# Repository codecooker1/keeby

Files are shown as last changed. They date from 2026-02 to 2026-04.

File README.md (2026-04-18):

# keeby
A custom ergonomic split keyboard made for HackClub Blueprint based on Corne, Lily58 and Sofle V2

# Routing PCB
more detailed svg and pdf available in PCB/plot

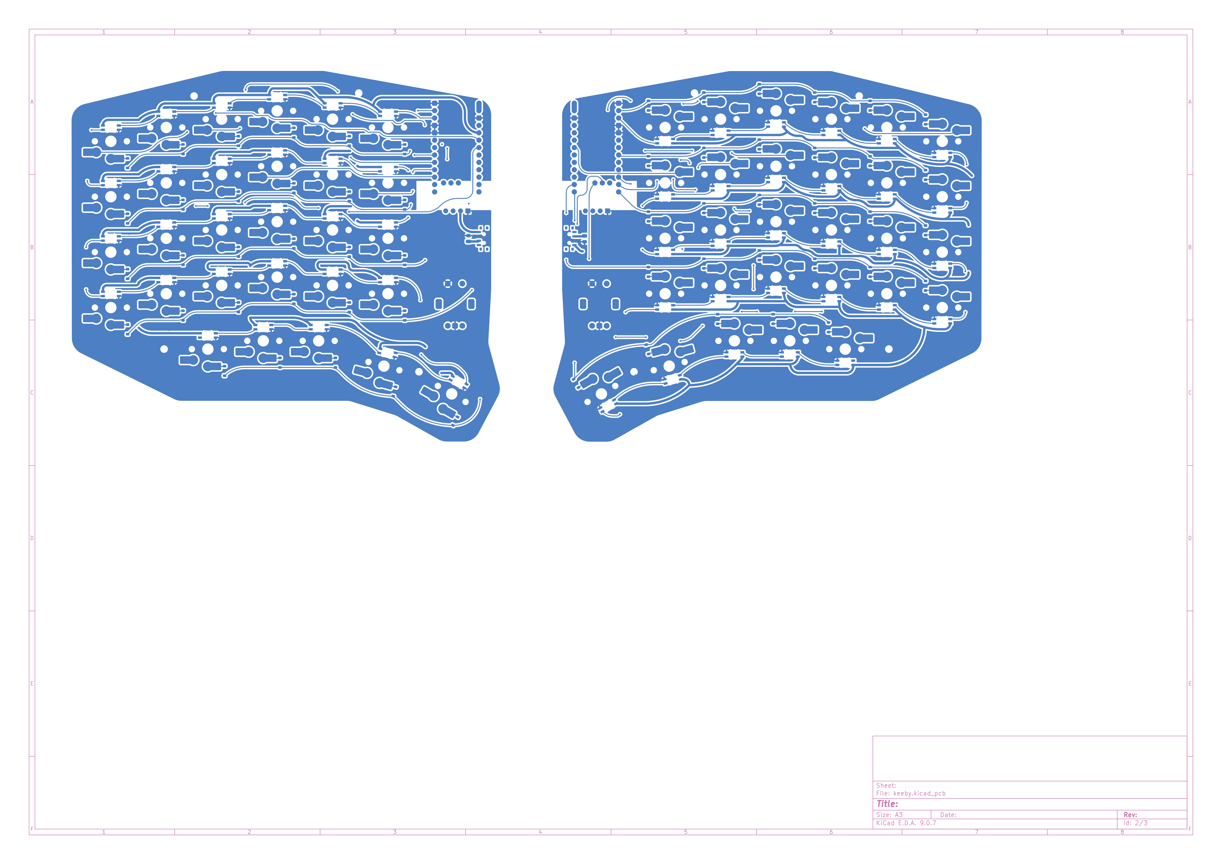
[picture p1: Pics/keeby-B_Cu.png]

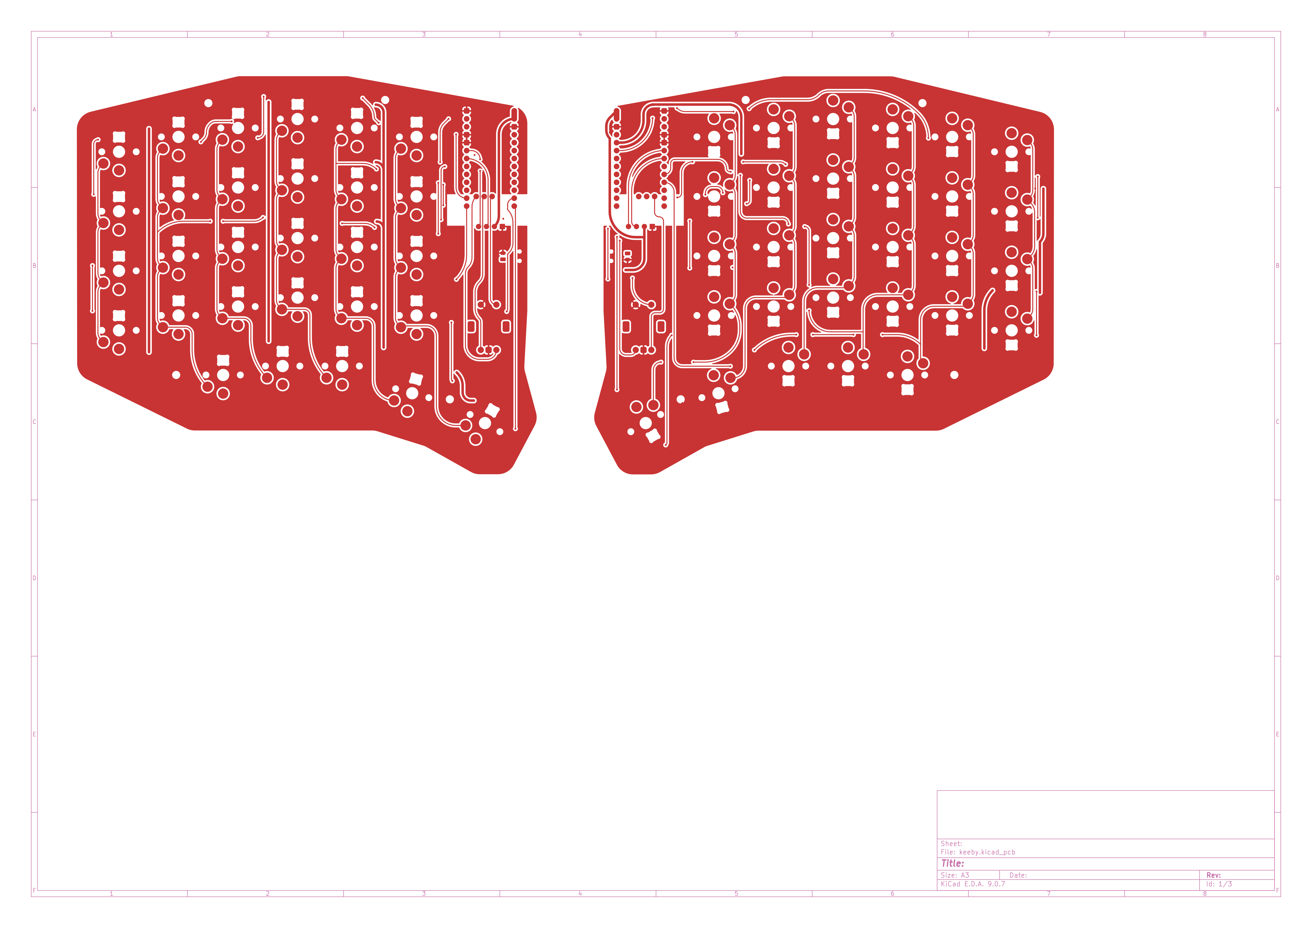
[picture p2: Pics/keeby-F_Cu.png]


# Schematic for the right half
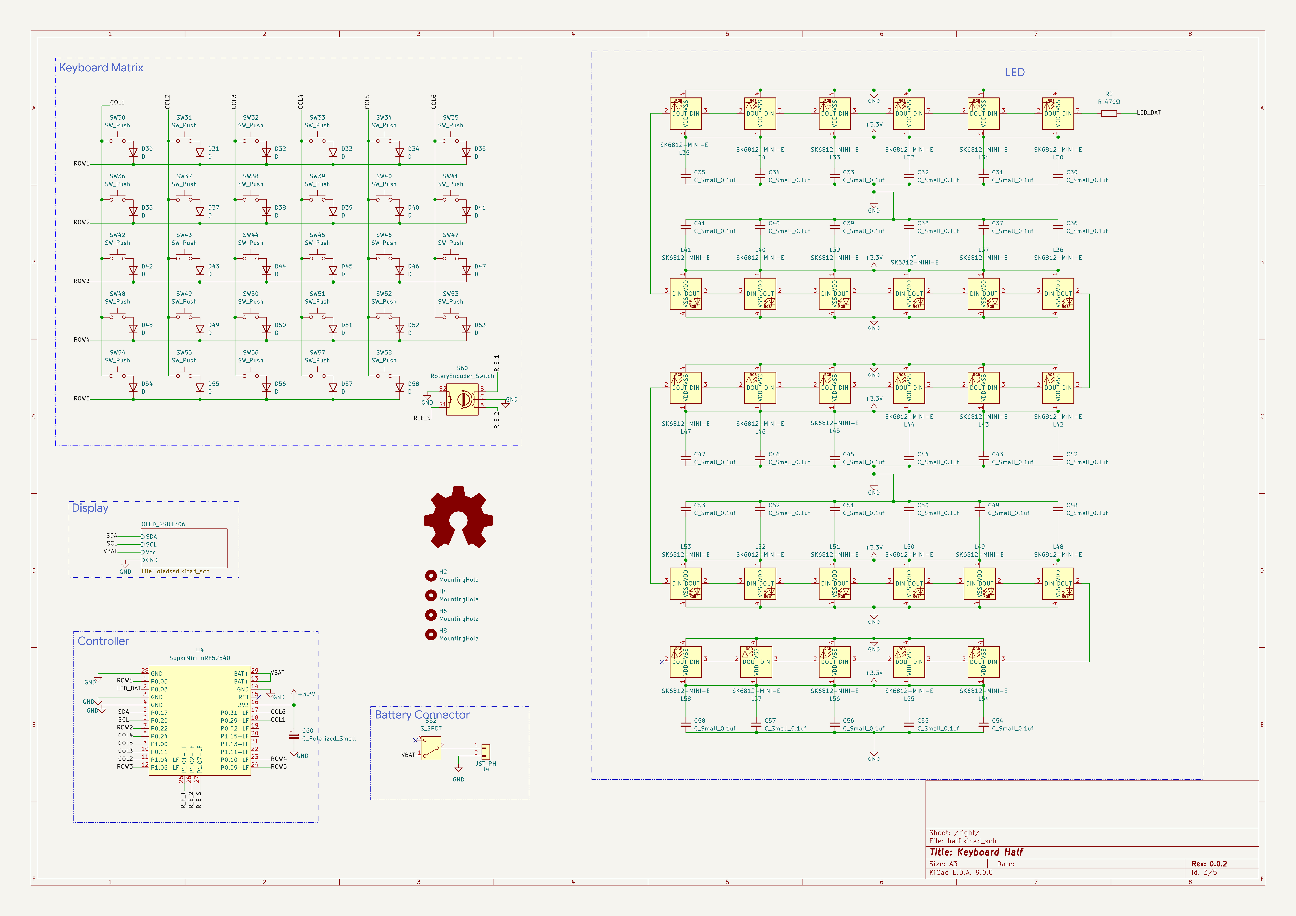
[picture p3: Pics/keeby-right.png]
keeb-right


# Schematic for the left half
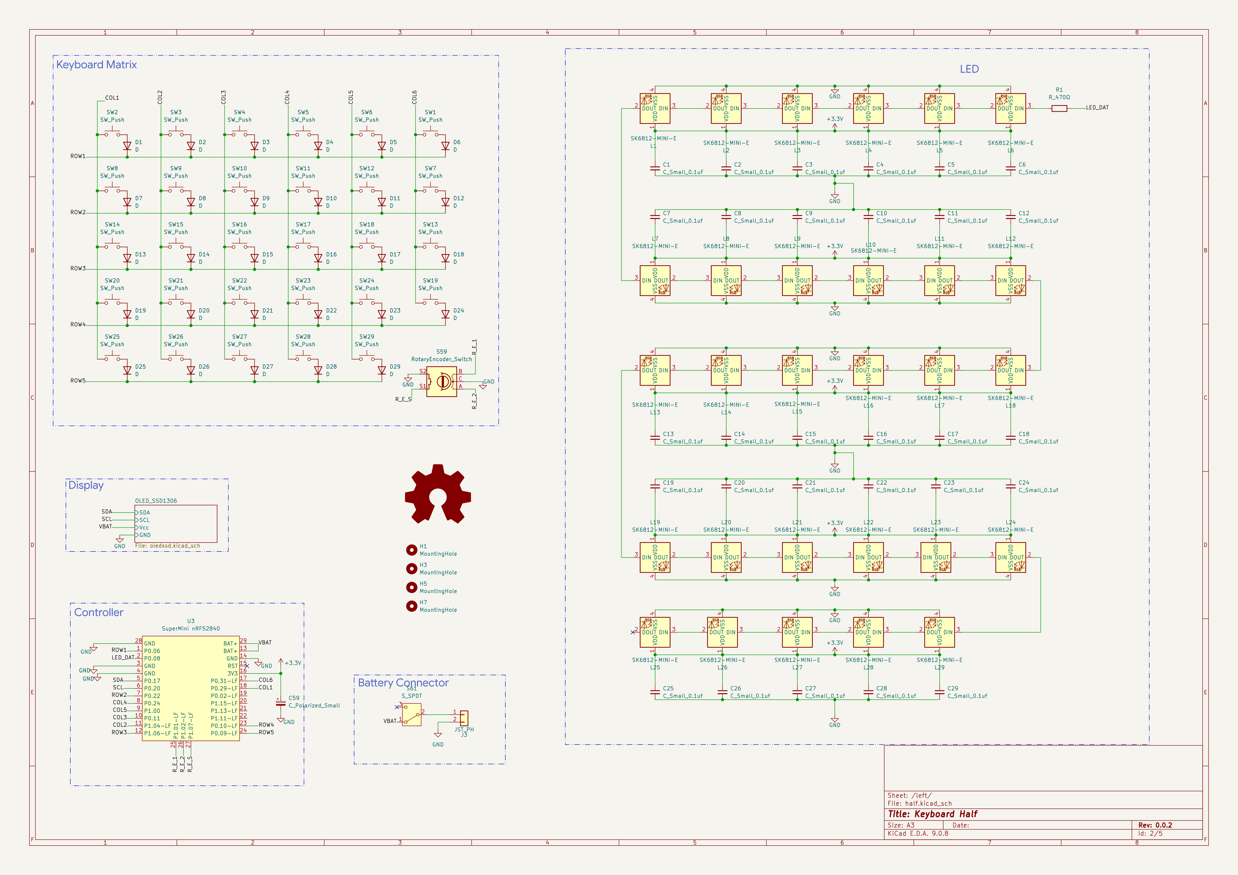
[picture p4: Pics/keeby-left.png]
keeb-left


# Casing??
Yup, made the casing in onshape. This is supposed to be 3D printed. You can find the 3D part files in the CAD/PrintParts folder. Here the FullCase is the full 3D model of the casing all parts included. Or you can find 3D models of individual parts in the CAD/PrintParts folder named by part.

Alternatively, you can view the Onshape design here: https://cad.onshape.com/documents/7252c9cab477090fa80b5ebe/w/9b87afb059b10e97f9e15540/e/26e119e6690b400aabda07c5

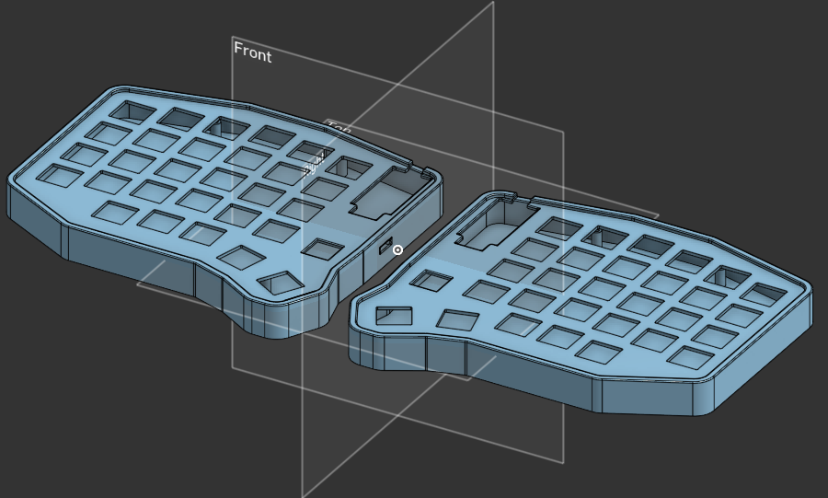
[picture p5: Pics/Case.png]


# How does the final PCB looks?
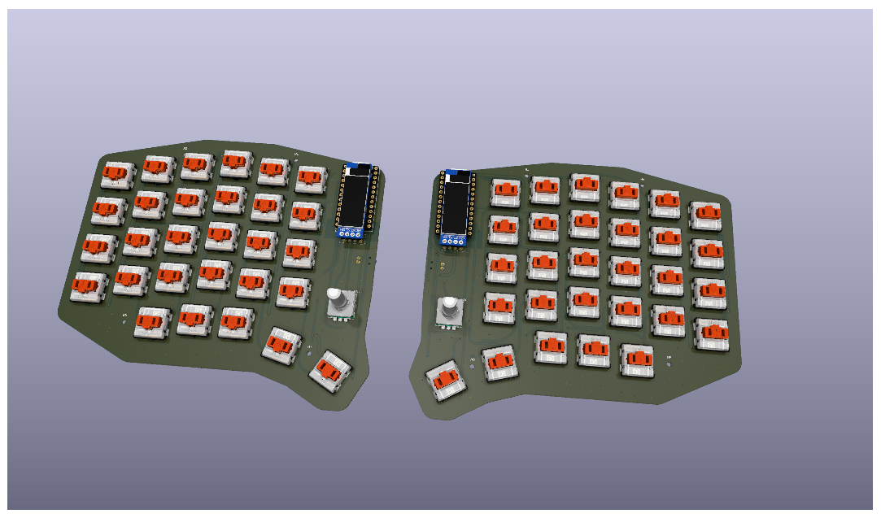
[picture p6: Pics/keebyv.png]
keeby

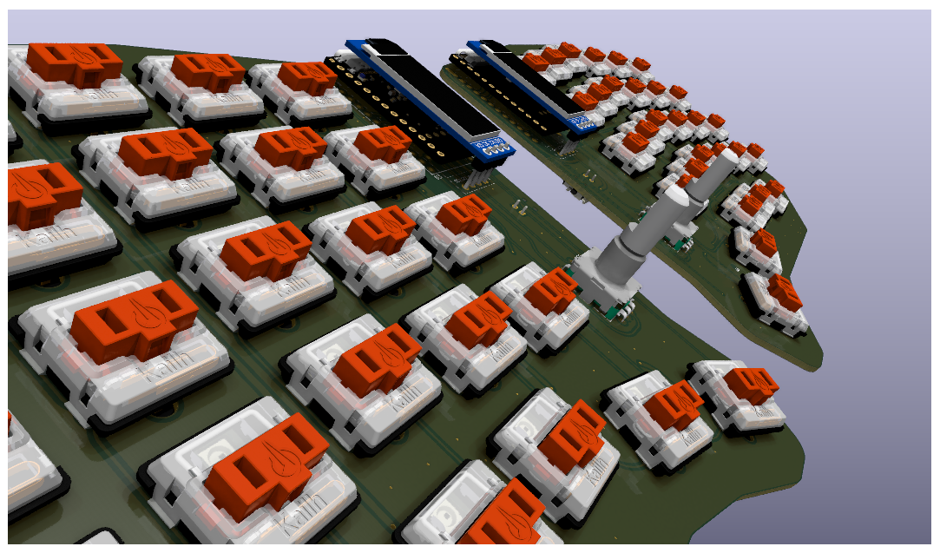
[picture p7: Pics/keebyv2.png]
keeby


For detailed view the .step files is in PCB/3dout/

# Final Assembled Keyboard
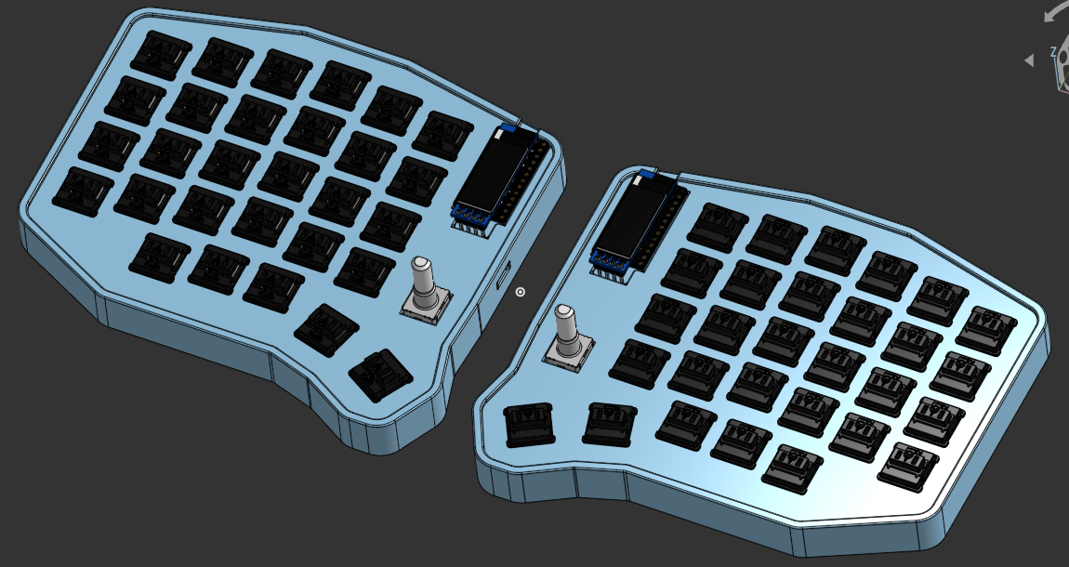
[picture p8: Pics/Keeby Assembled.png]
keeby


# Detailed BOM of Keeby

| | Sourced | Placed | References | Value | Footprint | Description | Quantity | Unit Price | Total Price | Link |
|----|---|---|---|---|---|---|---|---|---|---|
| 1  | | | L* | SK6812MINI-E | LED_choc_6028R-ROT | Reverse mount adressable LED (WS2812 protocol) SK6812-MINI-E | 58 | | $6.19 | https://www.aliexpress.com/item/1005007863635868.html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 |
| 2  | | | D* | D | D_SOD-123 | Diode | 100 | | $0.90 | https://www.aliexpress.com/item/1005005460442161.html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 |
| 3  | | | SW* | SW_Push | SW_choc_v1_HS_CPG135001S30_1u | Kailh Choc Mechanical Switch | 70 | | $21.45 | https://www.aliexpress.com/item/1005008751312031.html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 |
| 4  | | | SW59, SW60 | RotaryEncoder_Switch | ROT_Alps_EC11E-Switch | Rotary encoder, dual channel, incremental quadrate outputs, with switch | 2 | $0.00 | $2.00 | https://www.aliexpress.com/item/1005006136446310.html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 |
| 5  | | | SW61, SW62 | SW_SPDT | SW_SPDT_PCM12 | Switch, single pole double throw | 2 | $0.50 | $1.00 | https://www.aliexpress.com/item/32951447363.html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 |
| 6  | | | J1, J2 | Conn_01x04_Pin | SSD1306-0.91-OLED-4pin-128x32 | .91" SSD1306 OLED Display | 2 | $1.00 | $2.00 | https://www.alibaba.com/product-detail/0-91-inch-OLED-Module-White_1601154882218.html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 |
| 7  | | | J3, J4 | JST_PH | JST_PH_S2B-PH-K_1x02_P2.00mm_Horizontal | JST Connector for battery | 2 | | $1.00 | https://www.aliexpress.com/item/4001235017139.html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 |
| 8  | | | N/A | Hotswap Socket | N/A | Kailh Choc Mechanical Switch Hotswap Socket | 58 | | $7.00 | https://www.aliexpress.com/item/32901654130.html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 |
| 9  | | | N/A | Choc Keycaps | N/A | Choc Keycaps Transparent 1u | 70 | | $14.00 | https://www.aliexpress.com/item/1005010282783838.html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 |
| 10 | | | N/A | LiPo Battery | N/A | LiPo Battries 1200 mAh | 2 | $1.60 | $3.20 | https://www.daraz.com.bd/products/jst-37v-1200mah-783448-lipo-i447238909-s2140245262.html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 |
| 11 | | | U3,U4 | | SuperMini nRF52840 | Supermini NRF52840 | 2 | $3.00 | $6.00 | https://www.alibaba.com/product-detail/Promicro-NRF52840-Development-Board-Compatible-with_1601439610830.html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 |
| 12 | | | N/A | Choc Keycaps | N/A | Choc keycaps Black 1.75u | 2 | | $5.87 | https://www.aliexpress.com/item/1005005916325764.html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{%22order%22%3A%2237%22%2C%22eval%22%3A%221%22%2C%22fromPage%22%3A%22search%22}&pdp_npi=6%40dis!AUD!9.46!1.50!!!6.25!0.99!%402140c1c317668196694054953ee7c0!12000034838215570!sea!AU!0!ABX!1!0!n_tag%3A-29910%3Bd%3A731fdbb5%3Bm03_new_user%3A-29895%3BpisId%3A5000000187462935&curPageLogUid=hfCDIVYR2pPX&utparam-url=scene%3Asearch|query_from%3A|x_object_id%3A1005005916325764|_p_origin_prod%3A |
| | | | | | | | TOTAL | | $70.61 | |

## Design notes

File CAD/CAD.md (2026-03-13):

The Case for this keyboard is made using Onshape.

You can view/inspect the case in onshape by following this link: https://cad.onshape.com/documents/932dc7db08e57313030c24ff/w/408d65841661d5e56a7be002/e/1b0f5b7b3b5ddf1dd94fa363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

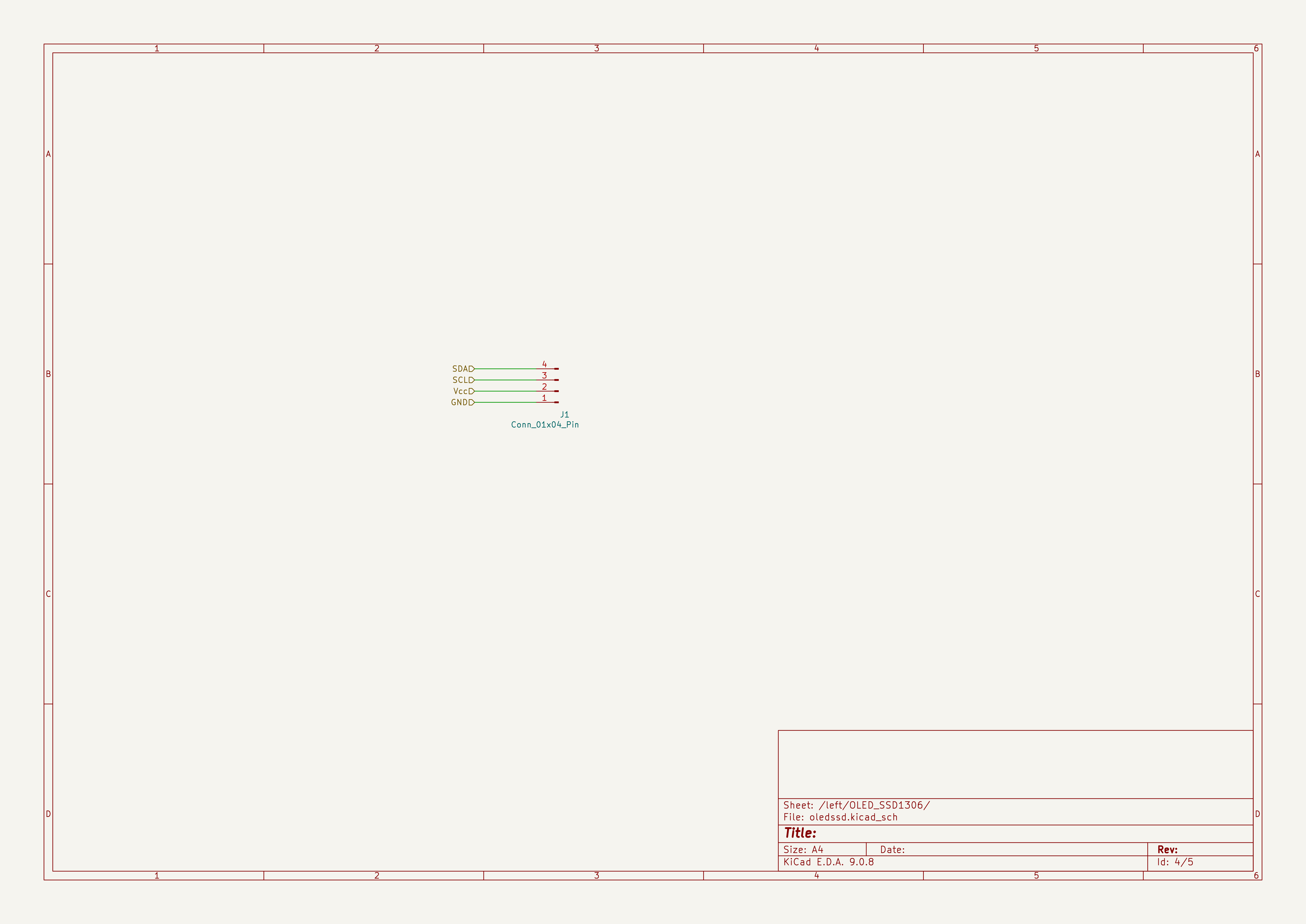
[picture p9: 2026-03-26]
Pics/keeby-left-OLED_SSD1306.png

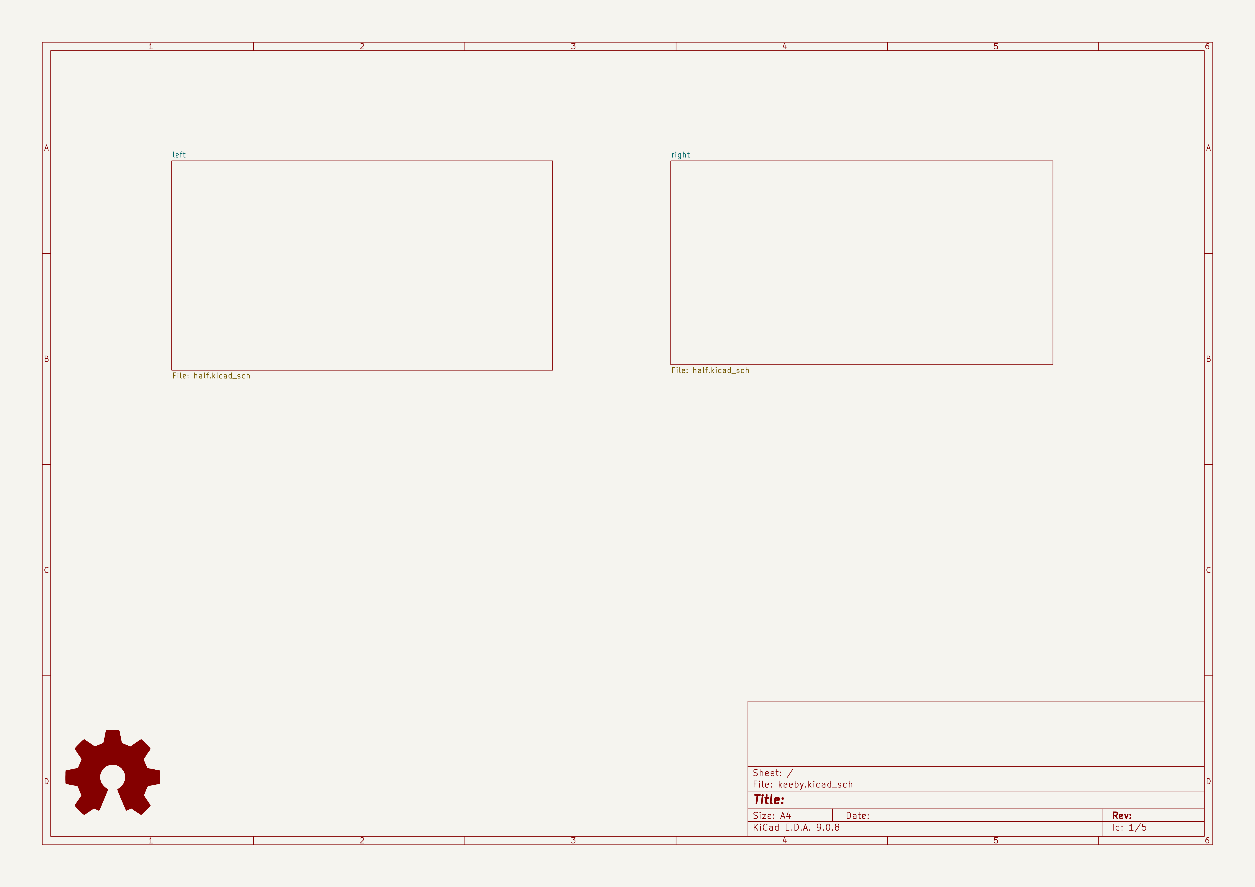
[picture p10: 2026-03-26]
Pics/keeby.png

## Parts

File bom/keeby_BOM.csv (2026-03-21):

 | Sourced | Placed | References | Value | Footprint | Description | Quantity | Unit Price | Total Price | Link
1 |  |  | L1, L2, L3, L4, L5, L6, L7, L8, L9, L10, L11, L12, L13, L14, L15, L16, L17, L18, L19, L20, L21, L22, L23, L24, L25, L26, L27, L28, L29, L30, L31, L32, L33, L34, L35, L36, L37, L38, L39, L40, L41, L42, L43, L44, L45, L46, L47, L48, L49, L50, L51, L52, L53, L54, L55, L56, L57, L58 | SK6812MINI-E | LED_choc_6028R-ROT | Reverse mount adressable LED (WS2812 protocol) SK6812-MINI-E | 58 |  | $6.19 | https://www.aliexpress.com/item/1005007863635868.html?mp=1
2 |  |  | D1, D2, D3, D4, D5, D6, D7, D8, D9, D10, D11, D12, D13, D14, D15, D16, D17, D18, D19, D20, D21, D22, D23, D24, D25, D26, D27, D28, D29, D30, D31, D32, D33, D34, D35, D36, D37, D38, D39, D40, D41, D42, D43, D44, D45, D46, D47, D48, D49, D50, D51, D52, D53, D54, D55, D56, D57, D58 | D | D_SOD-123 | Diode | 100 |  | $0.90 | https://www.aliexpress.com/item/1005005460442161.html?mp=1
3 |  |  | SW1, SW2, SW3, SW4, SW5, SW6, SW7, SW8, SW9, SW10, SW11, SW12, SW13, SW14, SW15, SW16, SW17, SW18, SW19, SW20, SW21, SW22, SW23, SW24, SW25, SW26, SW27, SW28, SW29, SW30, SW31, SW32, SW33, SW34, SW35, SW36, SW37, SW38, SW39, SW40, SW41, SW42, SW43, SW44, SW45, SW46, SW47, SW48, SW49, SW50, SW51, SW52, SW53, SW54, SW55, SW56, SW57, SW58 | SW_Push | SW_choc_v1_HS_CPG135001S30_1u | Kailh Choc Mechanical Switch | 58 | $0.40 | $23.20 | https://www.aliexpress.com/item/1005008751312031.html?mp=1
4 |  |  | SW59, SW60 | RotaryEncoder_Switch | ROT_Alps_EC11E-Switch | Rotary encoder, dual channel, incremental quadrate outputs, with switch | 2 | $0.31 | $0.62 | https://www.aliexpress.com/item/1005006136446310.html?mp=1
5 |  |  | SW61, SW62 | SW_SPDT | SW_SPDT_PCM12 | Switch, single pole double throw | 2 | $0.50 | $1.00 | https://www.aliexpress.com/item/32951447363.html?curPageLogUid=M9MqK9B1Ixso
6 |  |  | J1, J2 | Conn_01x04_Pin | SSD1306-0.91-OLED-4pin-128x32 | .91" SSD1306 OLED Display | 2 | $1.00 | $2.00 | https://www.alibaba.com/product-detail/0-91-inch-OLED-Module-White_1601154882218.html
7 |  |  | J3, J4 | JST_PH | JST_PH_S2B-PH-K_1x02_P2.00mm_Horizontal | JST Connector for battery | 2 | $0.50 | $1.00 | https://www.aliexpress.com/item/4001235017139.html?mp=1
8 |  |  | N/A | Hotswap Socket | N/A | Kailh Choc Mechanical Switch Hotswap Socket | 58 | $0.14 | $8.12 | https://www.aliexpress.com/item/32901654130.html?curPageLogUid=v5xv7rZ1f0eT
9 |  |  | N/A | Choc Keycaps | N/A | Choc Keycaps Transparent 1u | 70 | $17.56 | $17.56 | https://www.aliexpress.com/item/1005010282783838.html?mp=1
10 |  |  | N/A | LiPo Battery | N/A | LiPo Battries 1200 mAh | 2 | $2.60 | $5.20 | https://www.daraz.com.bd/products/jst-37v-1200mah-783448-lipo-i447238909-s2140245262.html?c=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
11 |  |  | U3,U4 |  | SuperMini nRF52840 | Supermini NRF52840 | 2 | $2.50 | $5.00 | https://www.alibaba.com/product-detail/Promicro-NRF52840-Development-Board-Compatible-with_1601439610830.html
12 |  |  | N/A | Choc Keycaps | N/A | Choc keycaps Black 1.75u | 2 |  | $5.87 | https://www.aliexpress.com/item/1005005916325764.html?curPageLogUid=hfCDIVYR2pPX&utparam-url=scene%3Asearch|query_from%3A|x_object_id%3A1005005916325764|_p_origin_prod%3A
 |  |  |  |  |  |  | TOTAL |  | $76.66

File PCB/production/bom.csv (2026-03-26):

Designator | Footprint | Quantity | Value | LCSC Part #
C1, C10, C11, C12, C13, C14, C15, C16, C17, C18, C19, C2, C20, C21, C22, C23, C24, C25, C26, C27, C28, C29, C3, C30, C31, C32, C33, C34, C35, C36, C37, C38, C39, C4, C40, C41, C42, C43, C44, C45, C46, C47, C48, C49, C5, C50, C51, C52, C53, C54, C55, C56, C57, C58, C6, C7, C8, C9 | 0805 | 58 | C_Small_0.1uF
C59, C60 | CP_EIA-7343-31_Kemet-D_HandSolder | 2 | C_Polarized_Small
D1, D10, D11, D12, D13, D14, D15, D16, D17, D18, D19, D2, D20, D21, D22, D23, D24, D25, D26, D27, D28, D29, D3, D30, D31, D32, D33, D34, D35, D36, D37, D38, D39, D4, D40, D41, D42, D43, D44, D45, D46, D47, D48, D49, D5, D50, D51, D52, D53, D54, D55, D56, D57, D58, D6, D7, D8, D9 | D_SOD-123 | 58 | D
J1, J2 | SSD1306-0.91-OLED-4pin-128x32 | 2 | Conn_01x04_Pin
J3, J4 | JST_PH_S2B-PH-K_1x02_P2.00mm_Horizontal | 2 | JST_PH
L1, L10, L11, L12, L13, L14, L15, L16, L17, L18, L19, L2, L20, L21, L22, L23, L24, L25, L26, L27, L28, L29, L3, L30, L31, L32, L33, L34, L35, L36, L37, L38, L39, L4, L40, L41, L42, L43, L44, L45, L46, L47, L48, L49, L5, L50, L51, L52, L53, L54, L55, L56, L57, L58, L6, L7, L8, L9 | LED_choc_6028R-ROT | 58 | SK6812-MINI-E
R1, R2 | 0805 | 2 | R_470Ω
S59, S60 | ROT_Alps_EC11E-Switch | 2 | RotaryEncoder_Switch
S61, S62 | SW_SPDT_PCM12 | 2 | S_SPDT
SW1, SW10, SW11, SW12, SW13, SW14, SW15, SW16, SW17, SW18, SW19, SW2, SW20, SW21, SW22, SW23, SW24, SW25, SW26, SW27, SW28, SW29, SW3, SW30, SW31, SW32, SW33, SW34, SW35, SW36, SW37, SW38, SW39, SW4, SW40, SW41, SW42, SW43, SW44, SW45, SW46, SW47, SW48, SW49, SW5, SW50, SW51, SW52, SW53, SW54, SW55, SW56, SW57, SW58, SW6, SW7, SW8, SW9 | SW_choc_v1_HS_CPG135001S30_1u | 58 | SW_Push

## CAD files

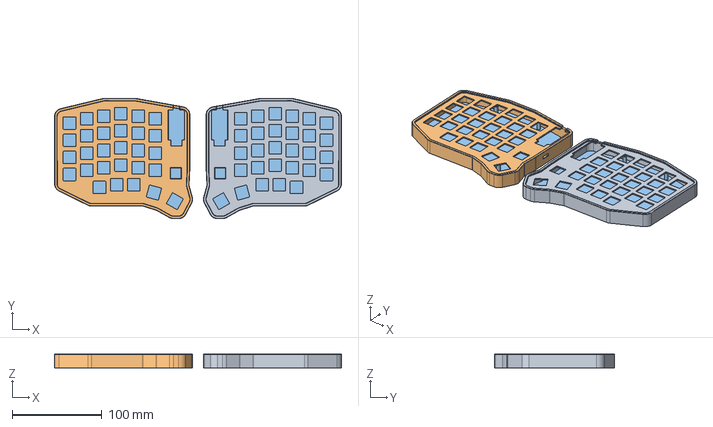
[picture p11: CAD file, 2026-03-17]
CAD/PrintParts/Full Case.step
319.2 x 133.8 x 15.3 mm

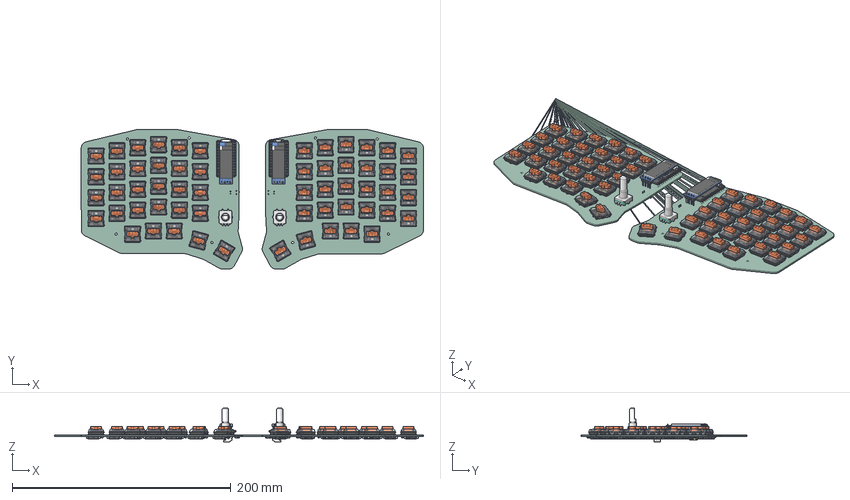
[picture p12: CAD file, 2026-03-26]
PCB/3dout/keeby_full.step
337.6 x 152.0 x 31.1 mm
ROT_EC11E x 2
nice!nano v1.0 x 2
mcu-chip-ic-2set-leg v1 x 2
LED_0603_1608Metric_ON v1 x 2
LED_0603_1608Metric_ON v1(Mirror) x 2
Crystal Oscillator v3 x 2
Crystal Oscillator v3 (1) x 2
usb4520-03-0-a v1 x 2
C0201 v1 x 56
C0402 v1 x 16
0603 v1 x 4
OLED_0.91_128x32 x 2
Pin Header 4 x 1 TH 2.54mm Pitch x 2
RESC-0603 x 26
2SD0601A x 2
JST_PH_S2B-PH-K_1x02_P2.00mm_Horizontal x 2
LED_SK6812MINI-E x 59
C_0805_2012Metric x 58
pin x 116
socket x 58
bottom_stabilizer x 58
contact x 58
pin1 x 58
pin2 x 58
top_stabilizer x 58
stabilizer x 58
stem_stabilizer x 58
shrunken_spring x 58
D_SOD-123 x 58
SW_SPDT_PCM12 x 2
CP_EIA-7343-31_Kemet-D x 2
R_0805_2012Metric x 2
keeby_PCB_1
keeby_PCB_2

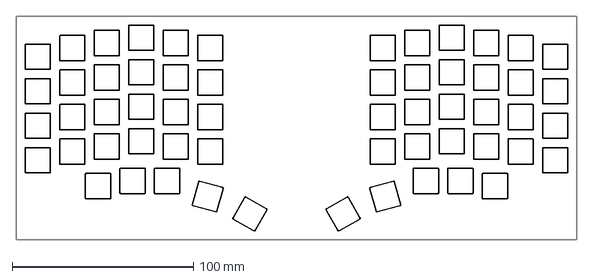
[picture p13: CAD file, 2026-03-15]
CAD/ImportParts/keeby-platev2.dxf
309.8 x 123.7 mm

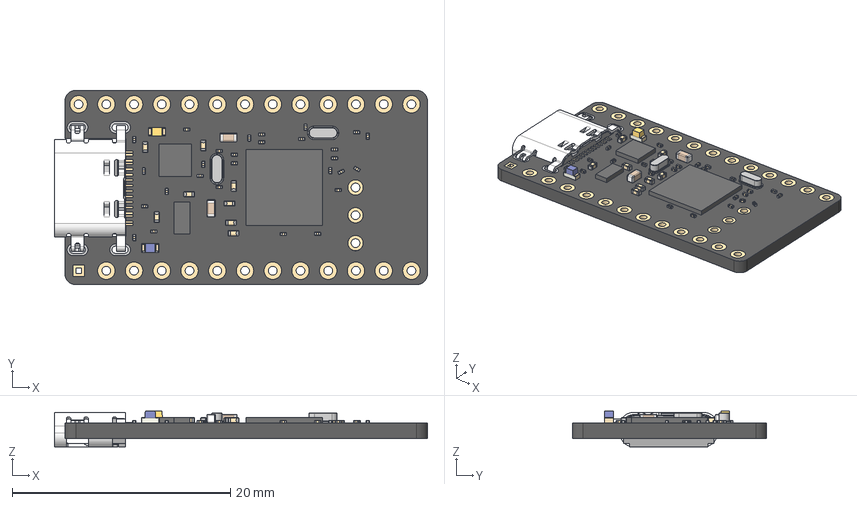
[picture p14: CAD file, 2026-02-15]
PCB/3dmodels/nice!nano v2.step
34.2 x 17.8 x 3.28 mm
nice!nano v1.0
SSOP16
LED_0603_1608Metric_ON
LED_0603_1608Metric_ON_1
Crystal Oscillator
Crystal Oscillator_1
usb4520-03-0-a_1
C0201 x 21
C0402 x 8
C0201_1 x 7

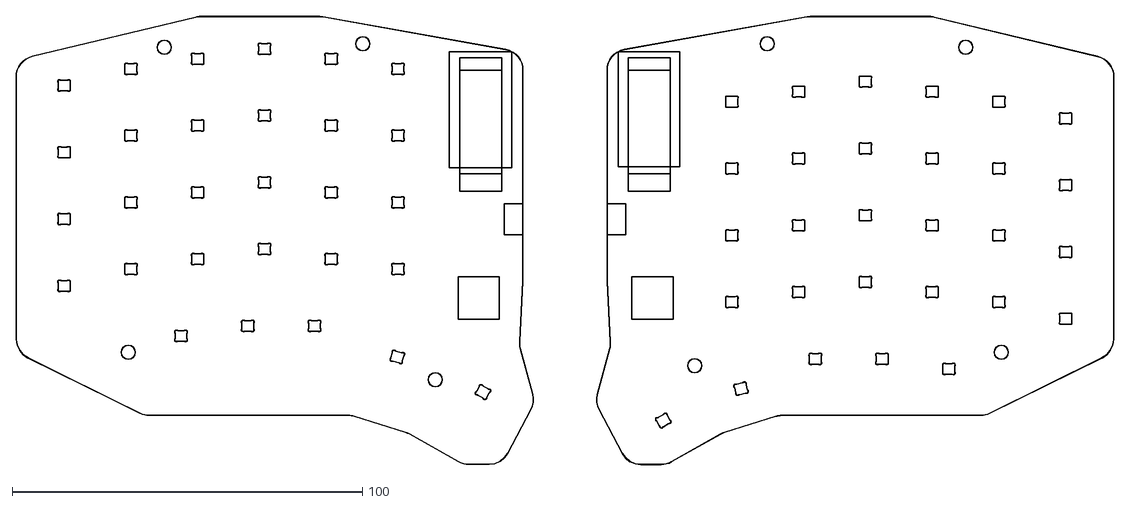
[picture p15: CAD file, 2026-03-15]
PCB/plot/dxf/keeby-Edge_Cuts.dxf
313.2 x 127.9

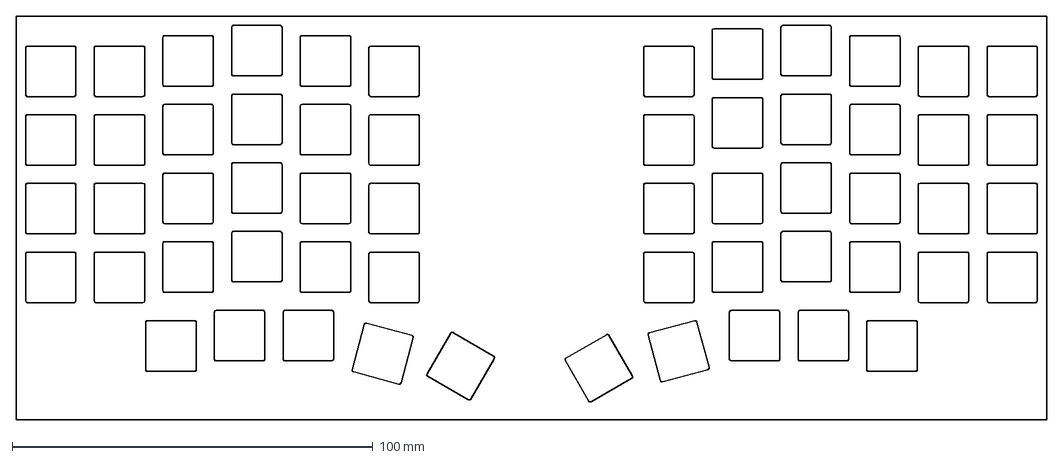
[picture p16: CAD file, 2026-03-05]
CAD/ImportParts/keeby-plate.dxf
285.8 x 111.9 mm

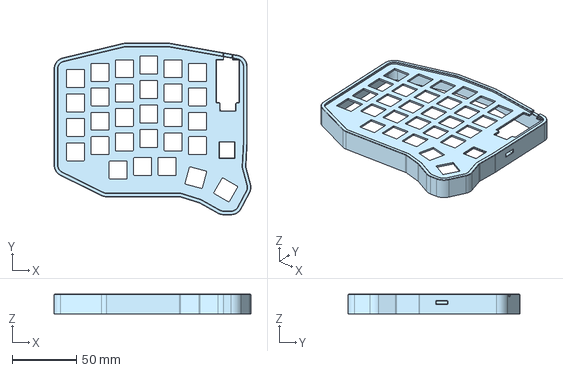
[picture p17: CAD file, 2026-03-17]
CAD/PrintParts/TopLeft.step
153.6 x 133.8 x 15.3 mm

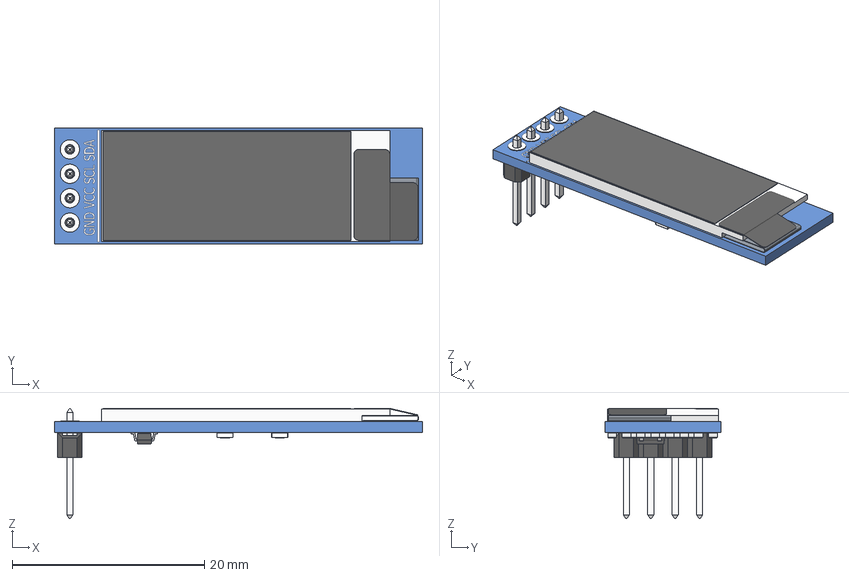
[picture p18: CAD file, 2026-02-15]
PCB/3dmodels/OLED_0.91_128x32.stp
38.3 x 12.1 x 11.5 mm
OLED_0.91_128x32
Pin Header 4 x 1 TH 2.54mm Pitch
RESC-0603 x 13
2SD0601A

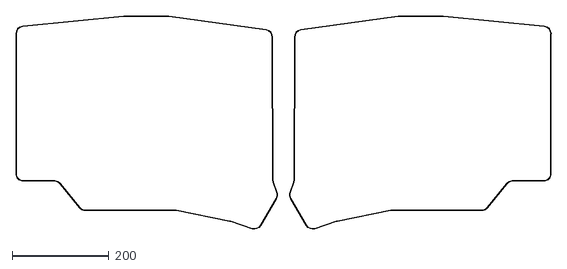
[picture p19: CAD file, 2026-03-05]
PCB/plot/dxf/keeb.dxf
1104.1 x 439.1

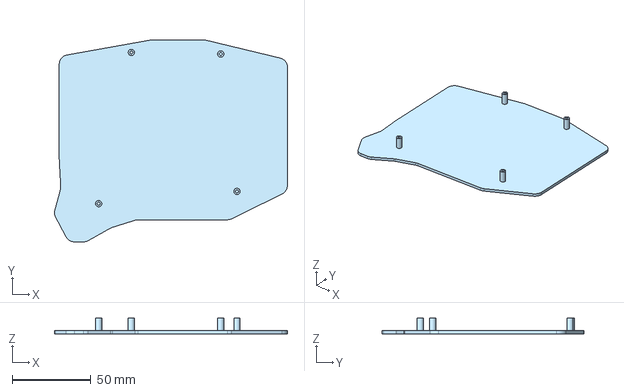
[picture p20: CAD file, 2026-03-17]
CAD/PrintParts/BottomRight.step
147.6 x 127.8 x 10.0 mm

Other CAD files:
PCB/3dout/keeby.step
CAD/PrintParts/TopRight.step
CAD/PrintParts/BottomLeft.step
CAD/PrintParts/FullCase.stl
PCB/3dout/keeby.stl

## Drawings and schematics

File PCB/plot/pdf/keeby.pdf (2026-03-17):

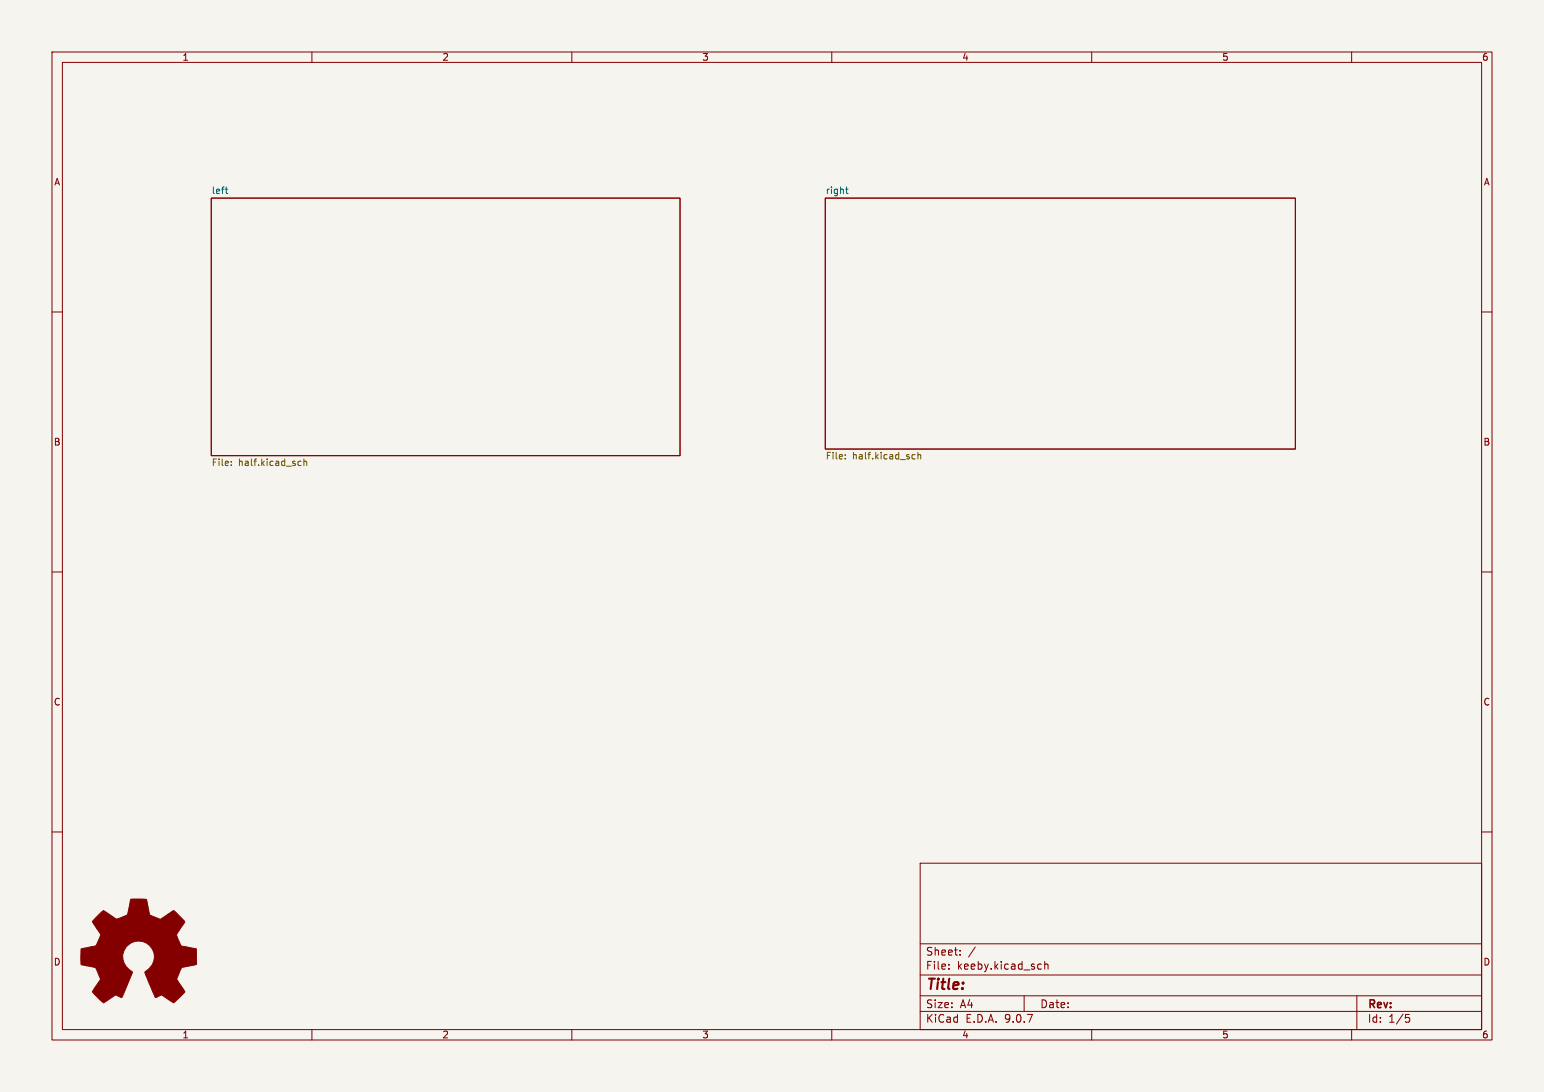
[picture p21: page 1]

Id: 1/5 Title: File: keeby.kicad_sch Sheet: /

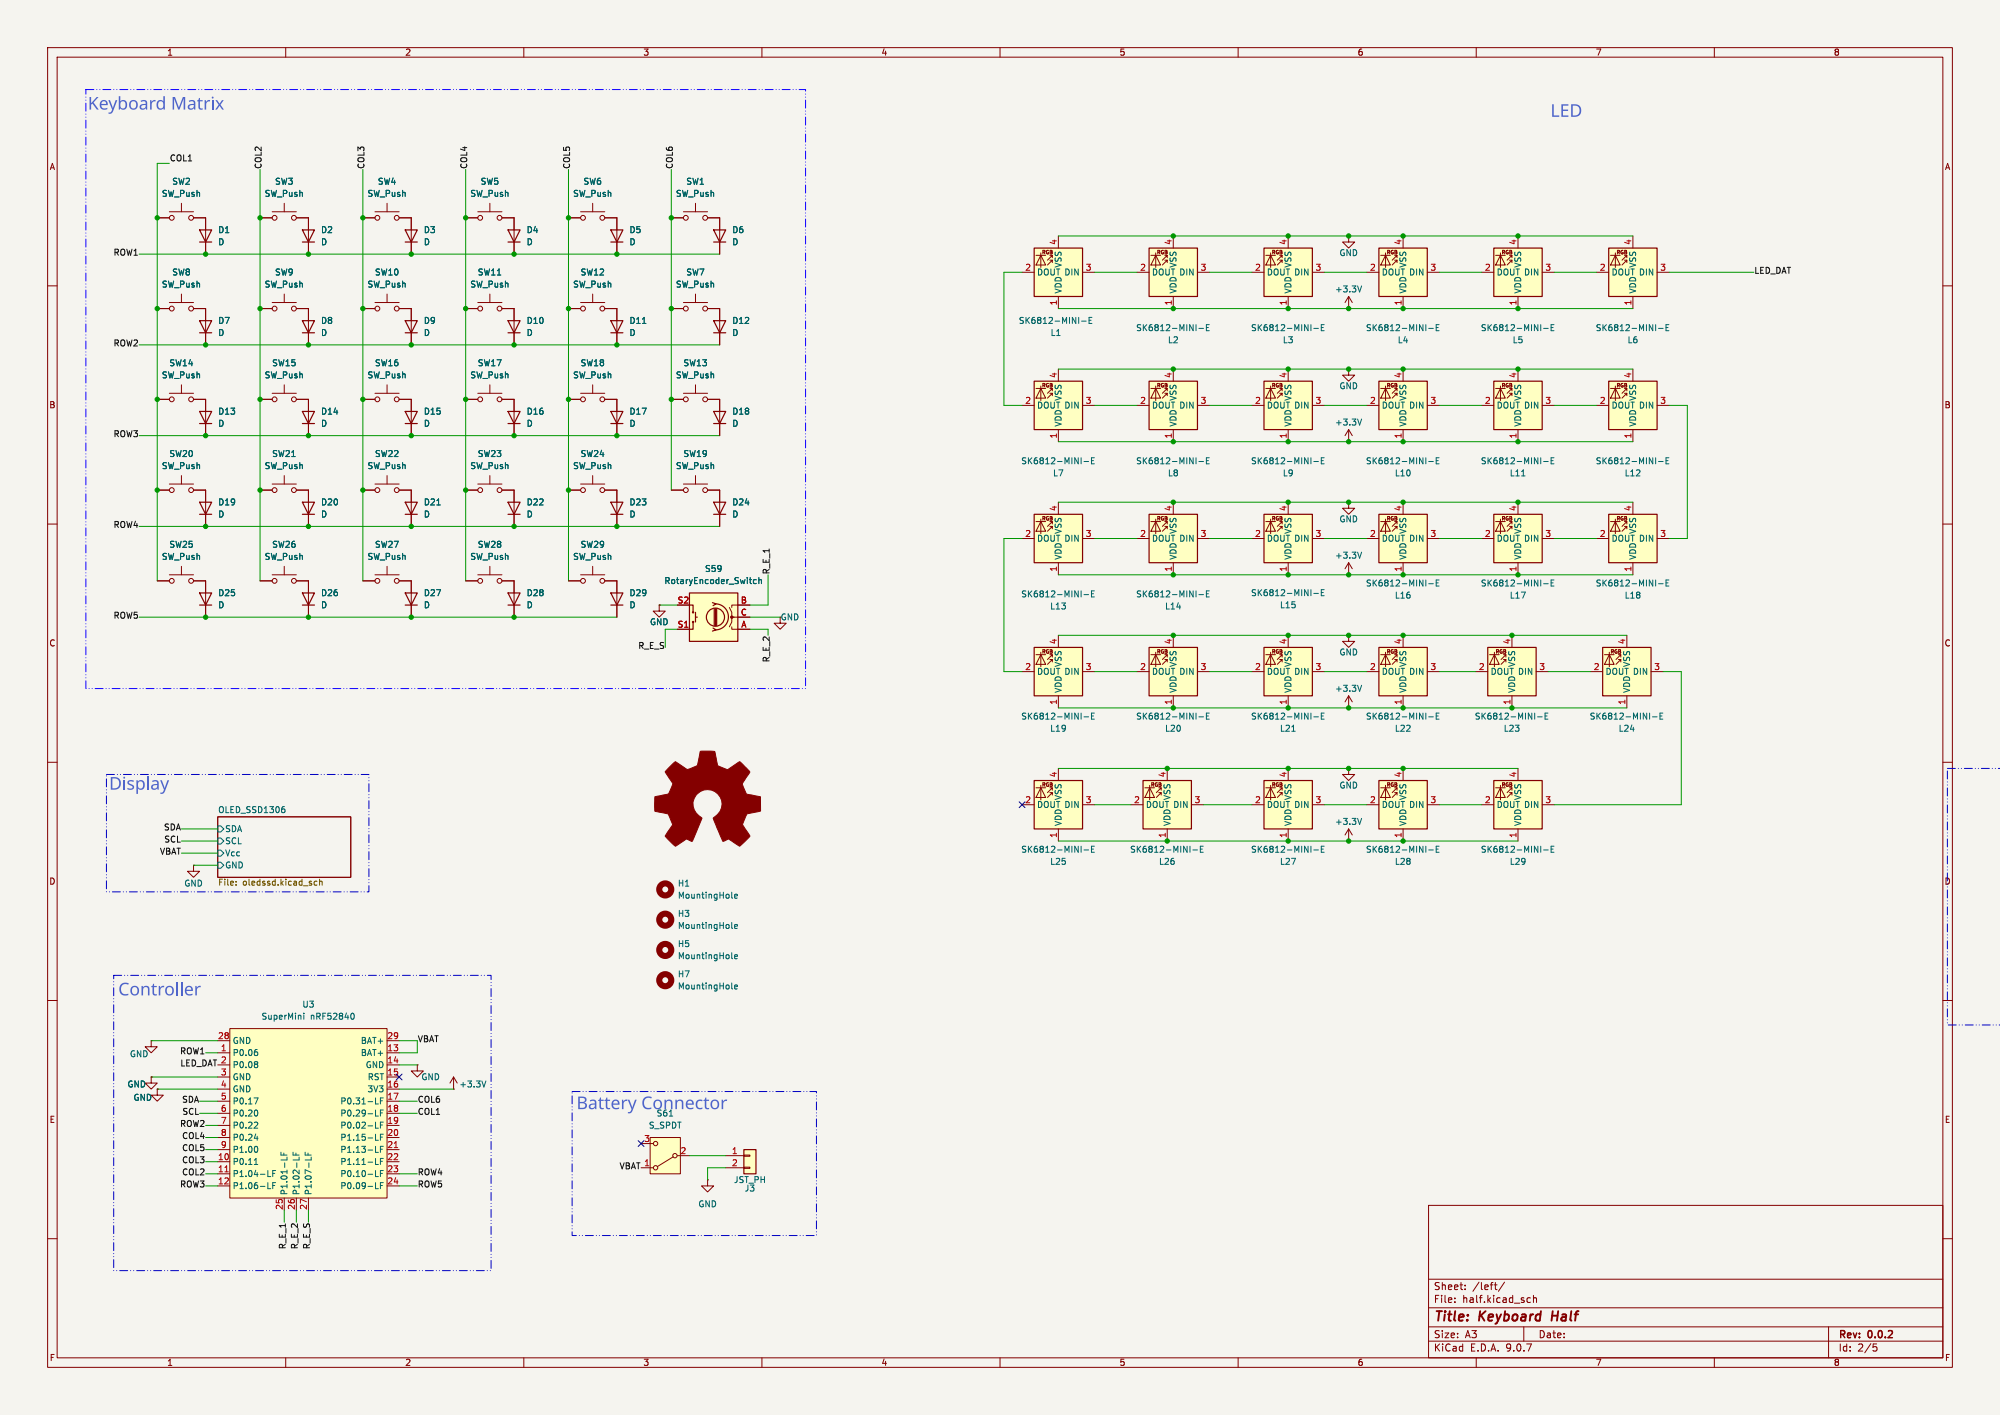
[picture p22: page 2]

H1 MountingHole H5 MountingHole H3 MountingHole H7 MountingHole

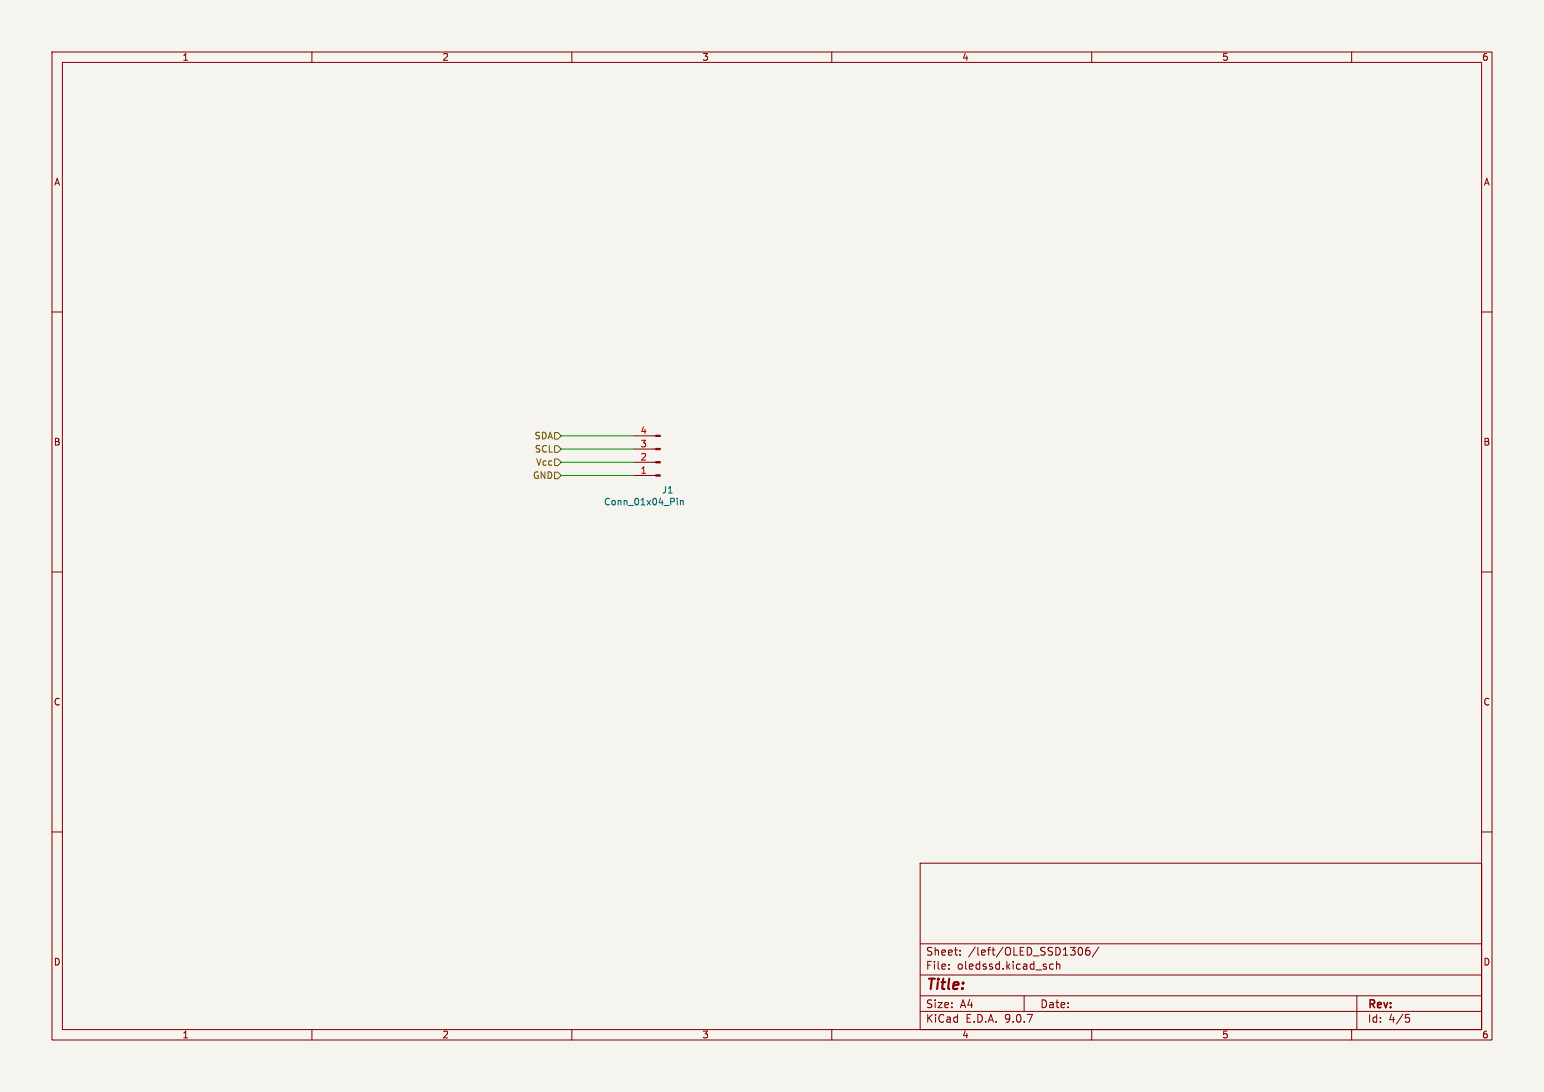
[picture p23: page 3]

Id: 4/5 Title: File: oledssd.kicad_sch Sheet: /left/OLED_SSD1306/

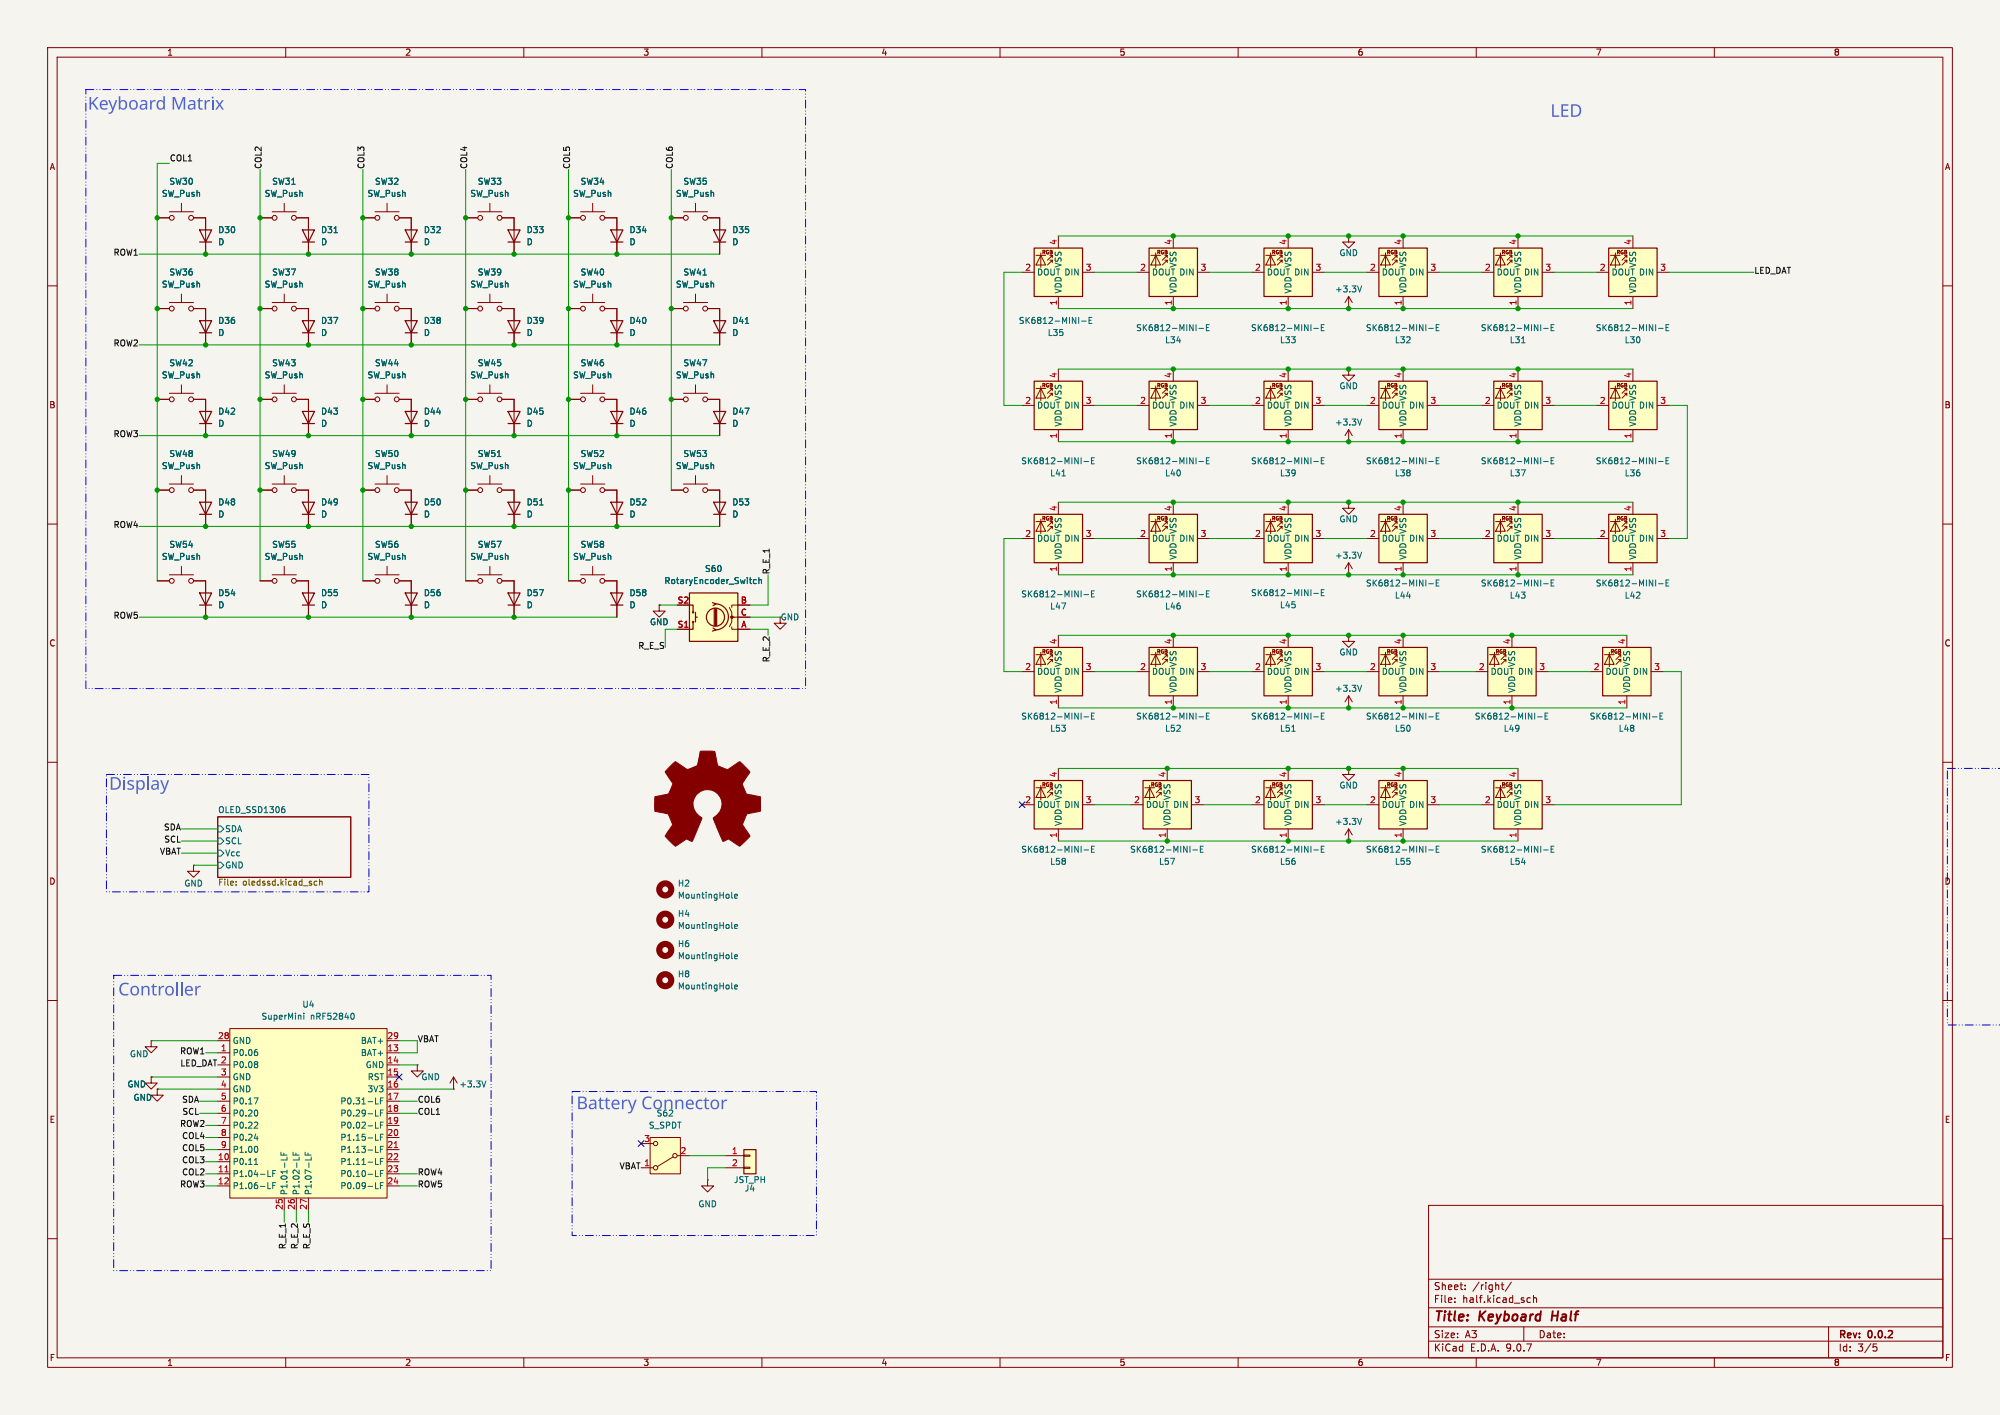
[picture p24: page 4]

H4 MountingHole H2 MountingHole H6 MountingHole H8 MountingHole

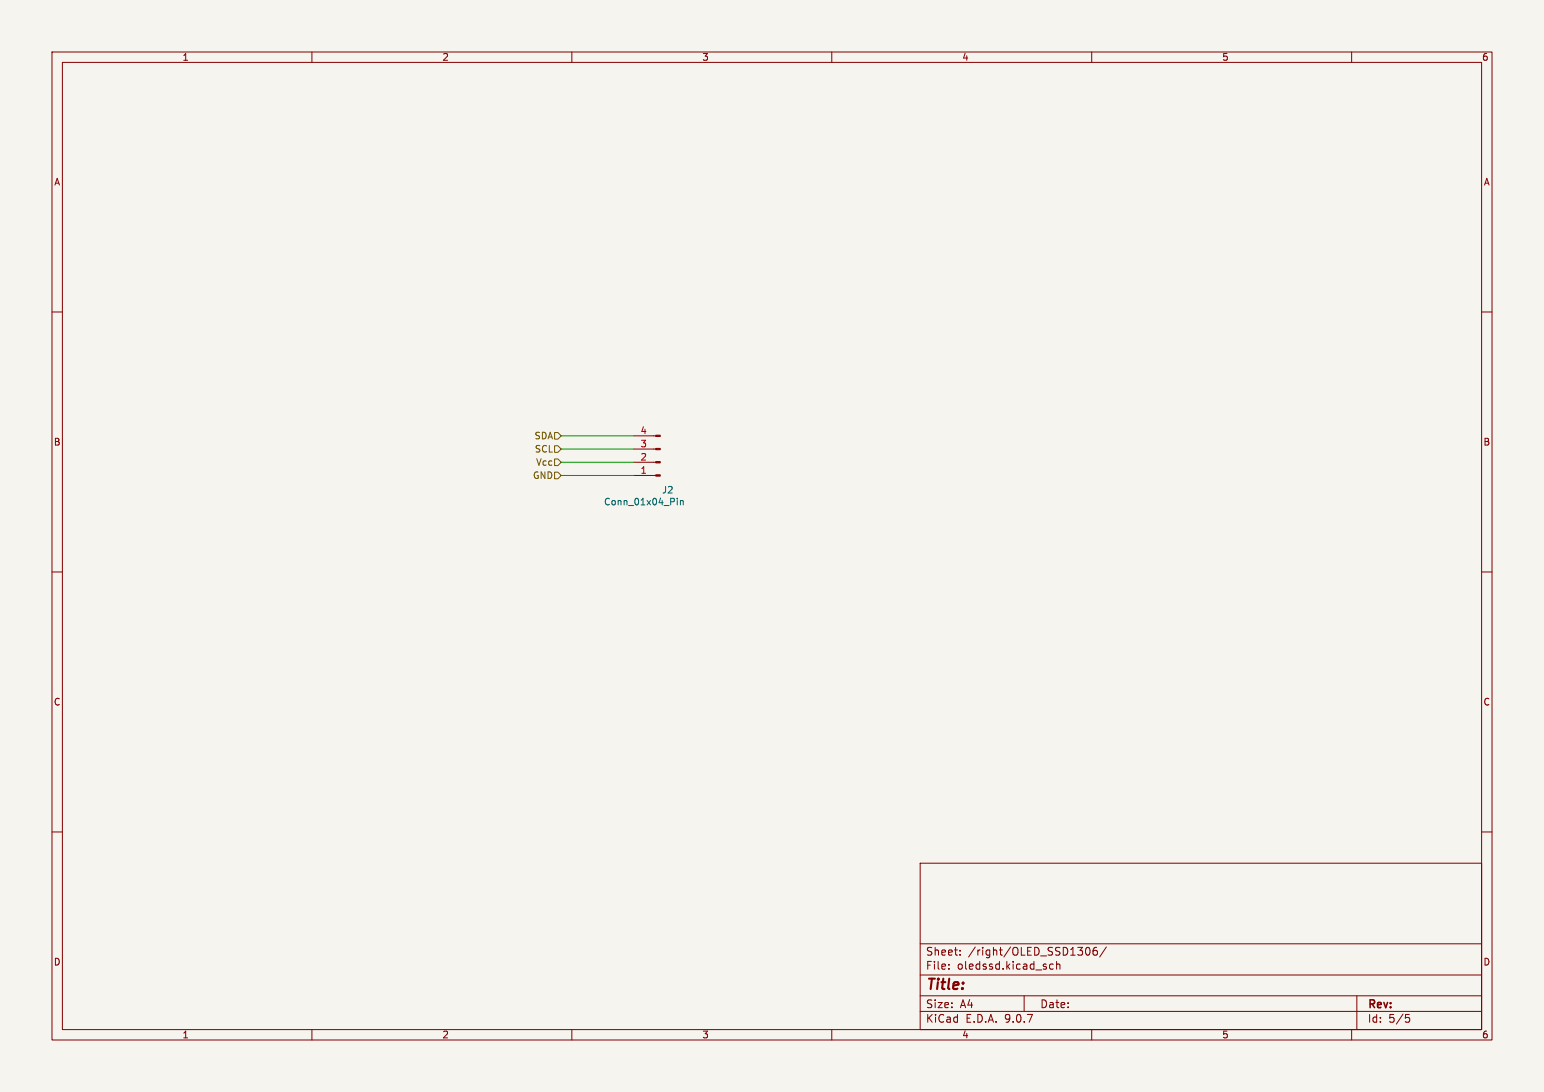
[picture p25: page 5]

Id: 5/5 Title: File: oledssd.kicad_sch Sheet: /right/OLED_SSD1306/

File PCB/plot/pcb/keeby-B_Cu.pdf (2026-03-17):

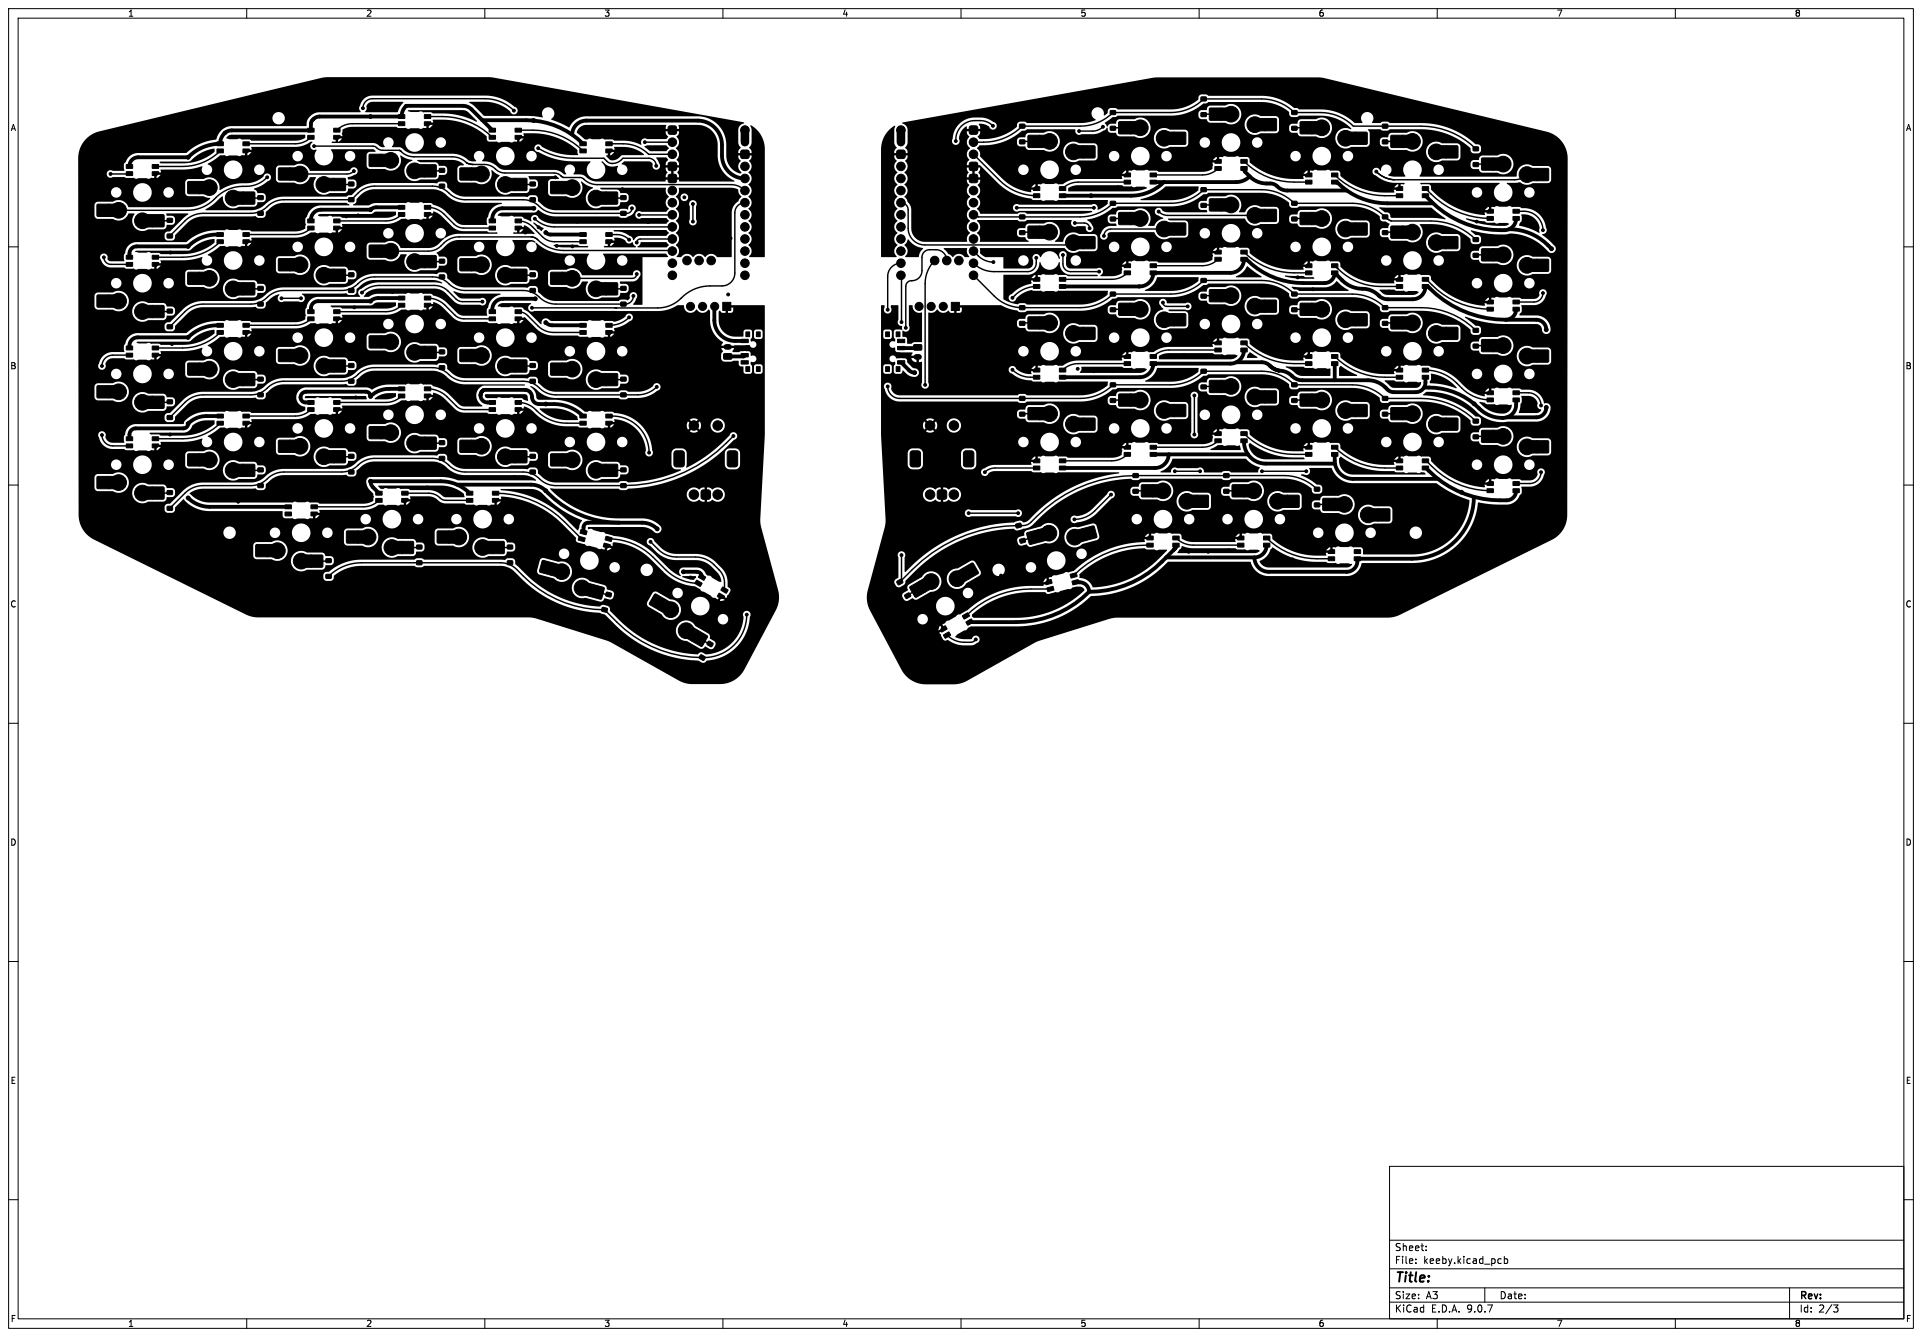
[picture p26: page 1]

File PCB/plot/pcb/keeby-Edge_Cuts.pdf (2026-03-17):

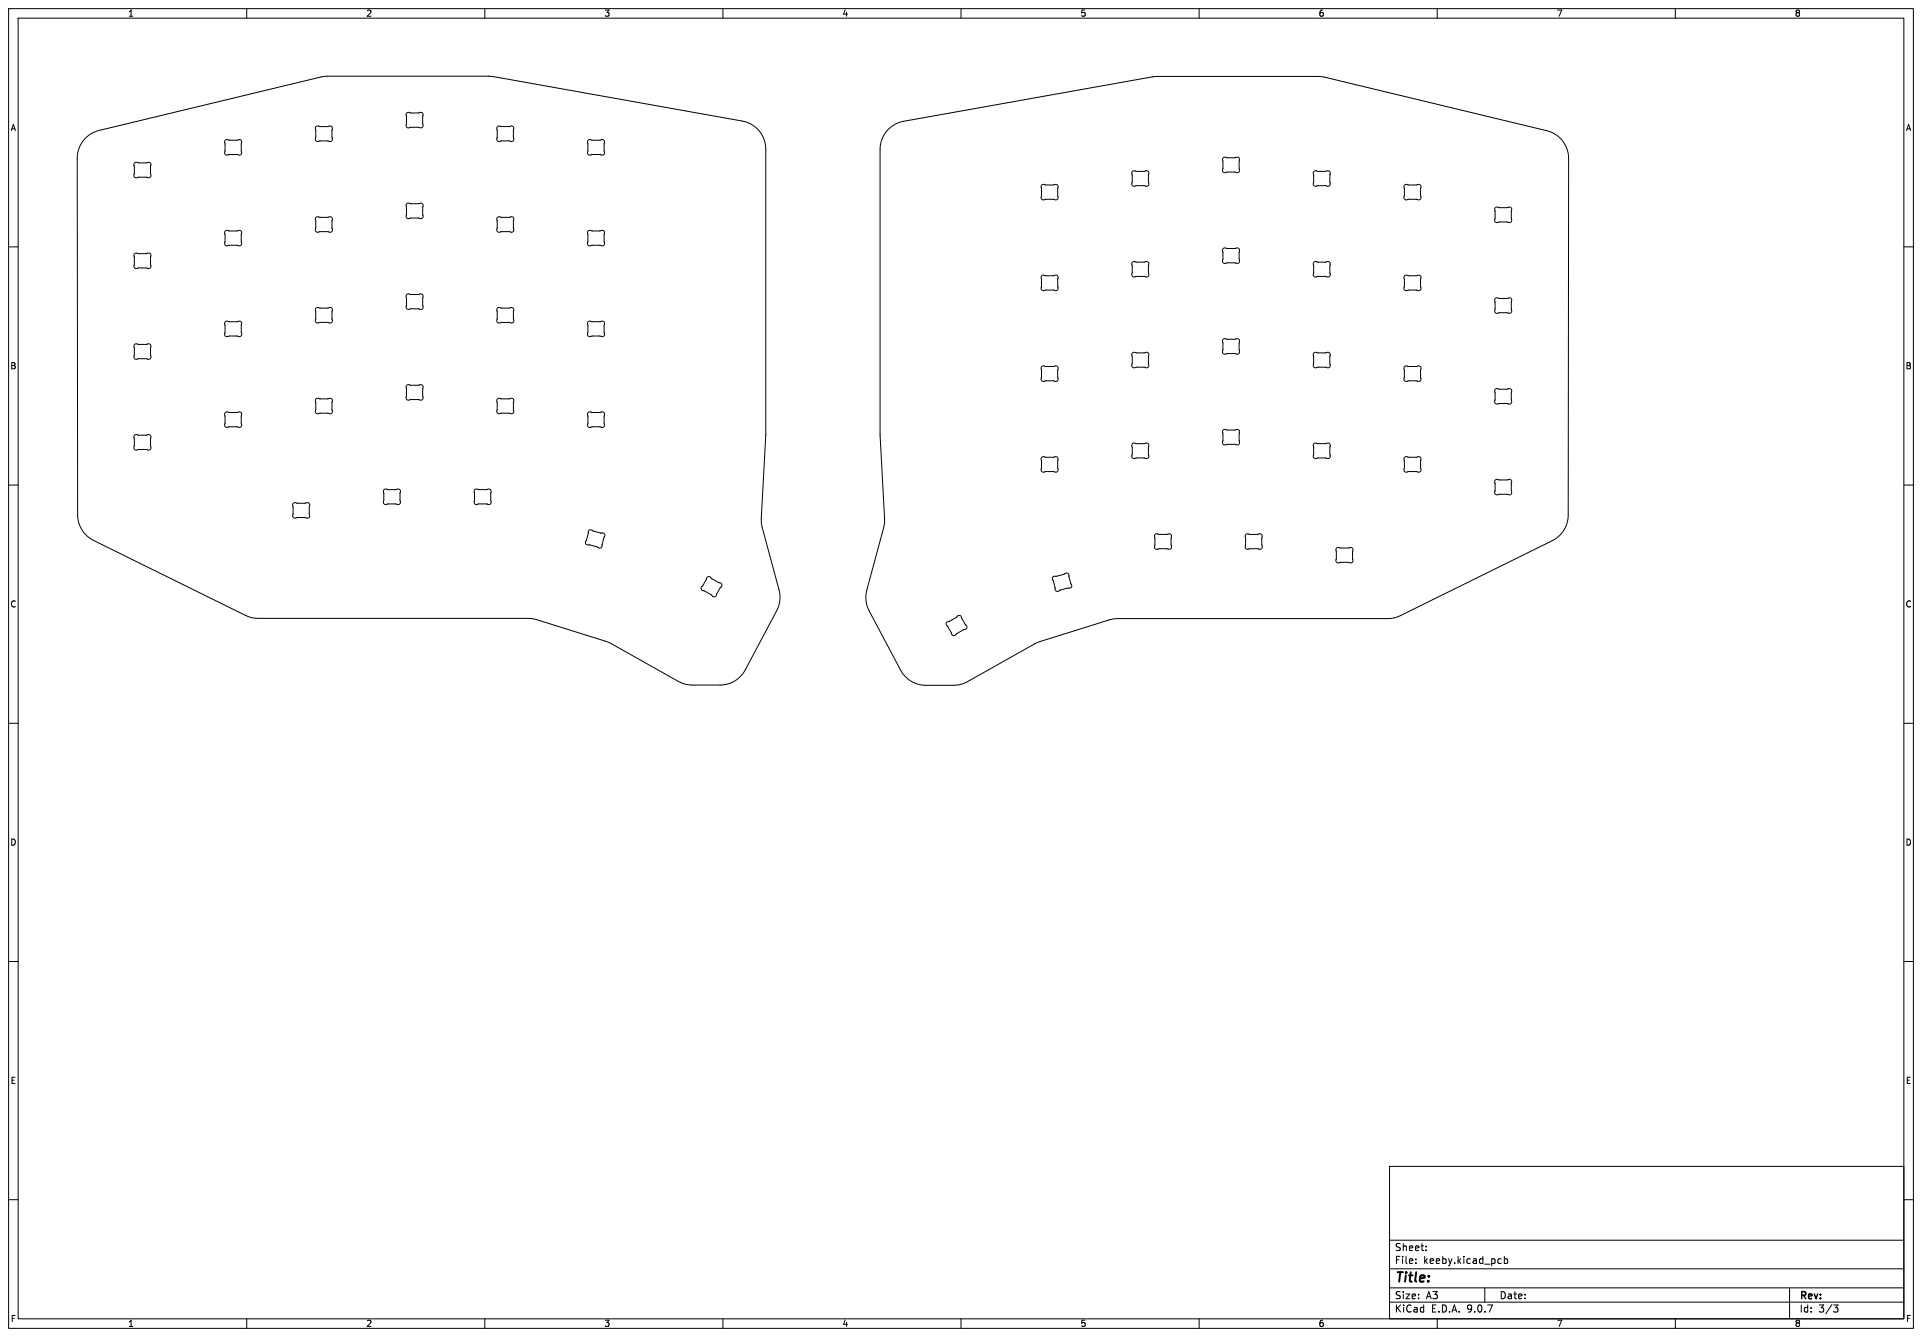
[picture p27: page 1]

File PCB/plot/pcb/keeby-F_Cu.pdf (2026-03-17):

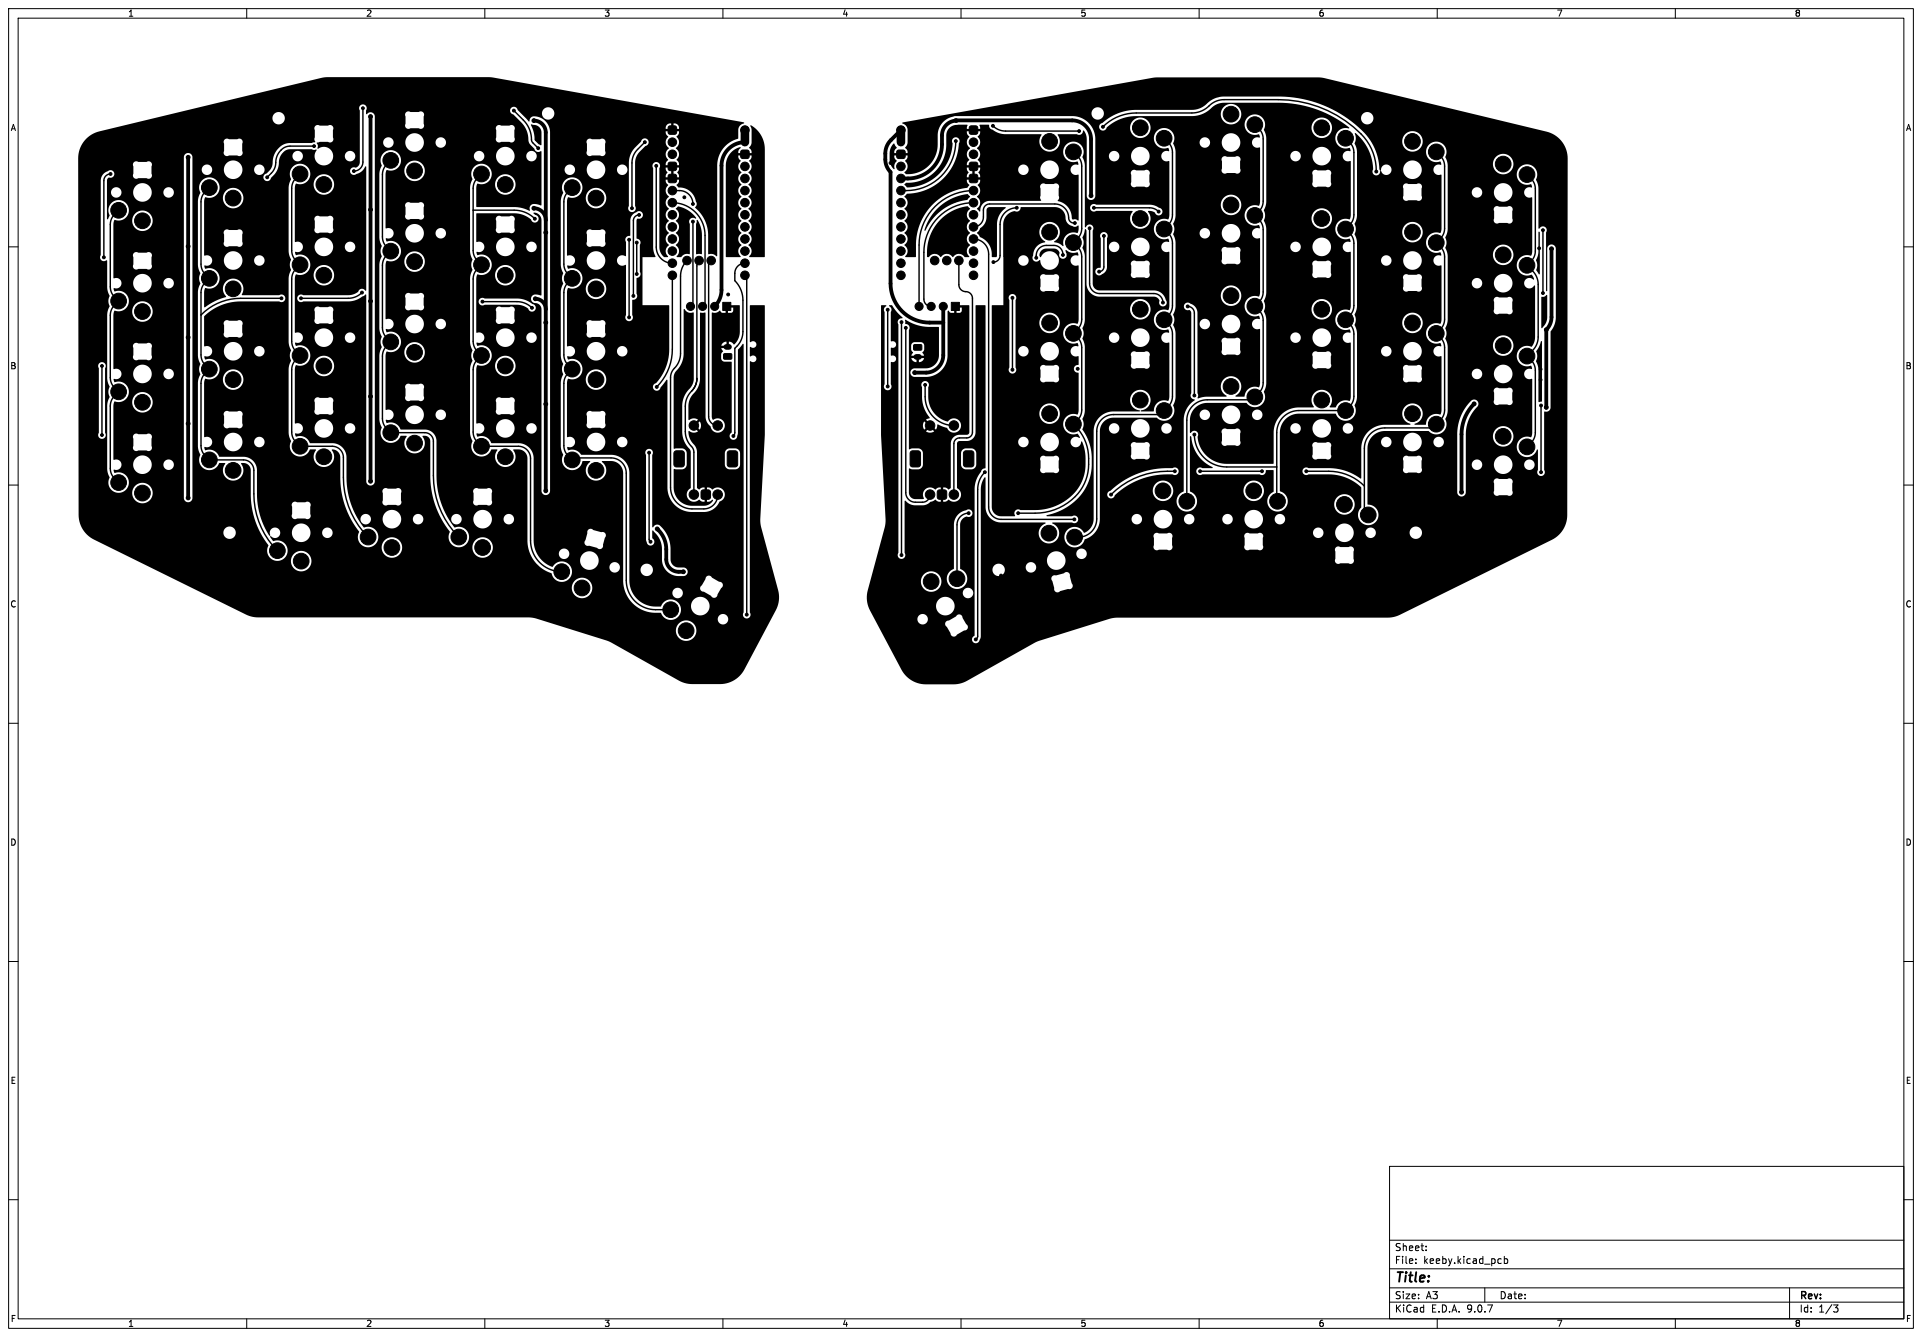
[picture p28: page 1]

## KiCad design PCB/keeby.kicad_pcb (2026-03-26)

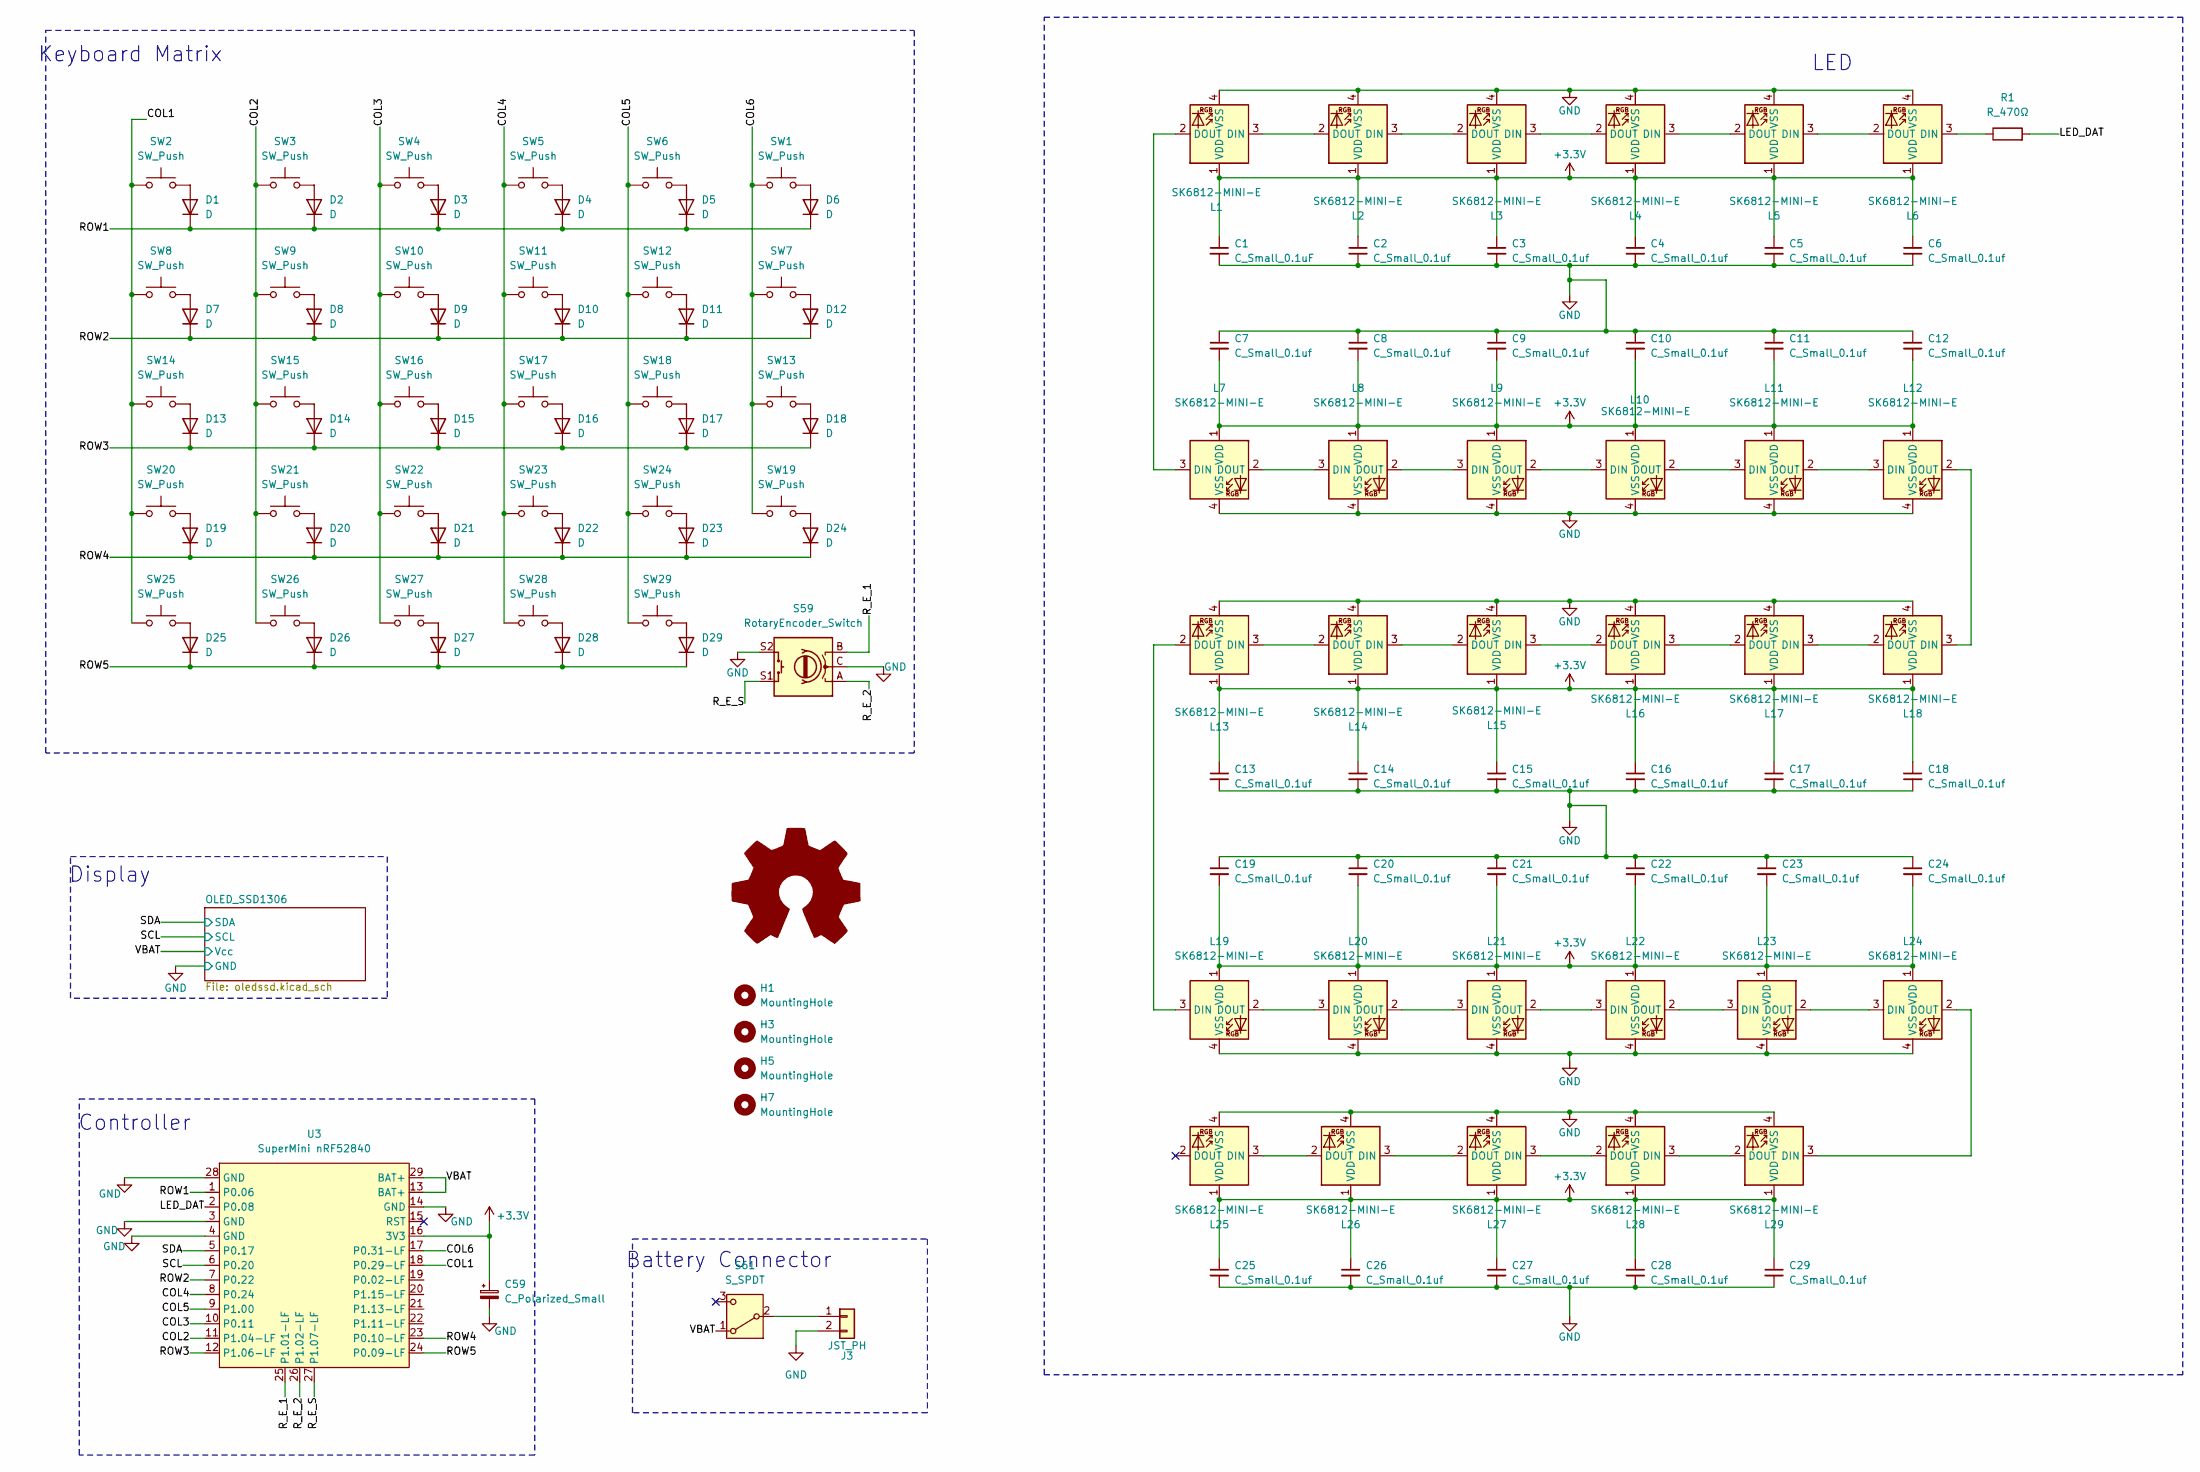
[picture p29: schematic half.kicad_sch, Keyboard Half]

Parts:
C1: C_Small_0.1uF; C_0805_2012Metric_Pad1.18x1.45mm_HandSolder
C2, C3, C4, C5, C6, C7, C8, C9, C10, C11, C12, C13, C14, C15, C16, C17, C18, C19, C20, C21, C22, C23, C24, C25, C26, C27, C28, C29: C_Small_0.1uf; C_0805_2012Metric_Pad1.18x1.45mm_HandSolder
C59: C_Polarized_Small; CP_EIA-7343-31_Kemet-D_HandSolder
D1, D2, D3, D4, D5, D6, D7, D8, D9, D10, D11, D12, D13, D14, D15, D16, D17, D18, D19, D20, D21, D22, D23, D24, D25, D26, D27, D28, D29: D; D_SOD-123
H1, H3, H5, H7: MountingHole; MountingHole_2.1mm
J3: JST_PH; JST_PH_S2B-PH-K_1x02_P2.00mm_Horizontal
L1, L2, L3, L4, L5, L6, L7, L8, L9, L10, L11, L12, L13, L14, L15, L16, L17, L18, L19, L20, L21, L22, L23, L24, L25, L26, L27, L28, L29: SK6812-MINI-E; LED_choc_6028R-ROT
R1: R_470Ω; R_0805_2012Metric_Pad1.20x1.40mm_HandSolder
S59: RotaryEncoder_Switch; ROT_Alps_EC11E-Switch
S61: S_SPDT; SW_SPDT_PCM12
SW1, SW2, SW3, SW4, SW5, SW6, SW7, SW8, SW9, SW10, SW11, SW12, SW13, SW14, SW15, SW16, SW17, SW18, SW19, SW20, SW21, SW22, SW23, SW24, SW25, SW26, SW27, SW28, SW29: SW_Push; SW_choc_v1_HS_CPG135001S30_1u
U3: SuperMini nRF52840; SuperMini_nRF52840_AH_USBup

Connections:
+3.3V: C1.1, C2.1, C3.1, C4.1, C5.1, C6.1, C7.2, C8.2, C9.2, C10.2, C11.2, C12.2, C13.1, C14.1, C15.1, C16.1, C17.1, C18.1, C19.2, C20.2, C21.2, C22.2, C23.2, C24.2, C25.1, C26.1, C27.1, C28.1, C29.1, C59.1, L1.1 (VDD), L2.1 (VDD), L3.1 (VDD), L4.1 (VDD), L5.1 (VDD), L6.1 (VDD), L7.1 (VDD), L8.1 (VDD), L9.1 (VDD), L10.1 (VDD), L11.1 (VDD), L12.1 (VDD), L13.1 (VDD), L14.1 (VDD), L15.1 (VDD), L16.1 (VDD), L17.1 (VDD), L18.1 (VDD), L19.1 (VDD), L20.1 (VDD), L21.1 (VDD), L22.1 (VDD), L23.1 (VDD), L24.1 (VDD), L25.1 (VDD), L26.1 (VDD), L27.1 (VDD), L28.1 (VDD), L29.1 (VDD), U3.16 (3V3); also elsewhere on the board
/left/COL1: SW2.1, SW8.1, SW14.1, SW20.1, SW25.1, U3.18 (P0.29-LF)
/left/COL2: SW3.1, SW9.1, SW15.1, SW21.1, SW26.1, U3.11 (P1.04-LF)
/left/COL3: SW4.1, SW10.1, SW16.1, SW22.1, SW27.1, U3.10 (P0.11)
/left/COL4: SW5.1, SW11.1, SW17.1, SW23.1, SW28.1, U3.8 (P0.24)
/left/COL5: SW6.1, SW12.1, SW18.1, SW24.1, SW29.1, U3.9 (P1.00)
/left/COL6: SW1.1, SW7.1, SW13.1, SW19.1, U3.17 (P0.31-LF)
/left/LED_DAT: R1.2, U3.2 (P0.08)
/left/ROW1: D1.1 (K), D2.1 (K), D3.1 (K), D4.1 (K), D5.1 (K), D6.1 (K), U3.1 (P0.06)
/left/ROW2: D7.1 (K), D8.1 (K), D9.1 (K), D10.1 (K), D11.1 (K), D12.1 (K), U3.7 (P0.22)
/left/ROW3: D13.1 (K), D14.1 (K), D15.1 (K), D16.1 (K), D17.1 (K), D18.1 (K), U3.12 (P1.06-LF)
/left/ROW4: D19.1 (K), D20.1 (K), D21.1 (K), D22.1 (K), D23.1 (K), D24.1 (K), U3.23 (P0.10-LF)
/left/ROW5: D25.1 (K), D26.1 (K), D27.1 (K), D28.1 (K), D29.1 (K), U3.24 (P0.09-LF)
/left/R_E_1: S59.B, U3.25 (P1.01-LF)
/left/R_E_2: S59.A, U3.26 (P1.02-LF)
/left/R_E_S: S59.S1, U3.27 (P1.07-LF)
/left/SCL: U3.6 (P0.20); also elsewhere on the board
/left/SDA: U3.5 (P0.17); also elsewhere on the board
/left/VBAT: S61.1 (A), U3.13 (BAT+), U3.29 (BAT+); also elsewhere on the board
GND: C1.2, C2.2, C3.2, C4.2, C5.2, C6.2, C7.1, C8.1, C9.1, C10.1, C11.1, C12.1, C13.2, C14.2, C15.2, C16.2, C17.2, C18.2, C19.1, C20.1, C21.1, C22.1, C23.1, C24.1, C25.2, C26.2, C27.2, C28.2, C29.2, C59.2, J3.2, L1.4 (VSS), L2.4 (VSS), L3.4 (VSS), L4.4 (VSS), L5.4 (VSS), L6.4 (VSS), L7.4 (VSS), L8.4 (VSS), L9.4 (VSS), L10.4 (VSS), L11.4 (VSS), L12.4 (VSS), L13.4 (VSS), L14.4 (VSS), L15.4 (VSS), L16.4 (VSS), L17.4 (VSS), L18.4 (VSS), L19.4 (VSS), L20.4 (VSS), L21.4 (VSS), L22.4 (VSS), L23.4 (VSS), L24.4 (VSS), L25.4 (VSS), L26.4 (VSS), L27.4 (VSS), L28.4 (VSS), L29.4 (VSS), S59.C, S59.S2, U3.3 (GND), U3.4 (GND), U3.14 (GND), U3.28 (GND); also elsewhere on the board
unnamed: D1.2 (A), SW2.2
unnamed: D2.2 (A), SW3.2
unnamed: D3.2 (A), SW4.2
unnamed: D4.2 (A), SW5.2
unnamed: D5.2 (A), SW6.2
unnamed: D6.2 (A), SW1.2
unnamed: D7.2 (A), SW8.2
unnamed: D8.2 (A), SW9.2
unnamed: D9.2 (A), SW10.2
unnamed: D10.2 (A), SW11.2
unnamed: D11.2 (A), SW12.2
unnamed: D12.2 (A), SW7.2
unnamed: D13.2 (A), SW14.2
unnamed: D14.2 (A), SW15.2
unnamed: D15.2 (A), SW16.2
unnamed: D16.2 (A), SW17.2
unnamed: D17.2 (A), SW18.2
unnamed: D18.2 (A), SW13.2
unnamed: D19.2 (A), SW20.2
unnamed: D20.2 (A), SW21.2
unnamed: D21.2 (A), SW22.2
unnamed: D22.2 (A), SW23.2
unnamed: D23.2 (A), SW24.2
unnamed: D24.2 (A), SW19.2
unnamed: D25.2 (A), SW25.2
unnamed: D26.2 (A), SW26.2
unnamed: D27.2 (A), SW27.2
unnamed: D28.2 (A), SW28.2
unnamed: D29.2 (A), SW29.2
unnamed: J3.1, S61.2 (B)
unnamed: L1.3 (DIN), L2.2 (DOUT)
unnamed: L1.2 (DOUT), L7.3 (DIN)
unnamed: L2.3 (DIN), L3.2 (DOUT)
unnamed: L3.3 (DIN), L4.2 (DOUT)
unnamed: L4.3 (DIN), L5.2 (DOUT)
unnamed: L5.3 (DIN), L6.2 (DOUT)
unnamed: L6.3 (DIN), R1.1
unnamed: L7.2 (DOUT), L8.3 (DIN)
unnamed: L8.2 (DOUT), L9.3 (DIN)
unnamed: L9.2 (DOUT), L10.3 (DIN)
unnamed: L10.2 (DOUT), L11.3 (DIN)
unnamed: L11.2 (DOUT), L12.3 (DIN)
unnamed: L12.2 (DOUT), L18.3 (DIN)
unnamed: L13.3 (DIN), L14.2 (DOUT)
unnamed: L13.2 (DOUT), L19.3 (DIN)
unnamed: L14.3 (DIN), L15.2 (DOUT)
unnamed: L15.3 (DIN), L16.2 (DOUT)
unnamed: L16.3 (DIN), L17.2 (DOUT)
unnamed: L17.3 (DIN), L18.2 (DOUT)
unnamed: L19.2 (DOUT), L20.3 (DIN)
unnamed: L20.2 (DOUT), L21.3 (DIN)
unnamed: L21.2 (DOUT), L22.3 (DIN)
unnamed: L22.2 (DOUT), L23.3 (DIN)
unnamed: L23.2 (DOUT), L24.3 (DIN)
unnamed: L24.2 (DOUT), L29.3 (DIN)
unnamed: L25.3 (DIN), L26.2 (DOUT)
unnamed: L26.3 (DIN), L27.2 (DOUT)
unnamed: L27.3 (DIN), L28.2 (DOUT)
unnamed: L28.3 (DIN), L29.2 (DOUT)

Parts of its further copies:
C30, C31, C32, C33, C34, C36, C37, C38, C39, C40, C41, C42, C43, C44, C45, C46, C47, C48, C49, C50, C51, C52, C53, C54, C55, C56, C57, C58: C_Small_0.1uf; C_0805_2012Metric_Pad1.18x1.45mm_HandSolder
C35: C_Small_0.1uF; C_0805_2012Metric_Pad1.18x1.45mm_HandSolder
C60: C_Polarized_Small; CP_EIA-7343-31_Kemet-D_HandSolder
D30, D31, D32, D33, D34, D35, D36, D37, D38, D39, D40, D41, D42, D43, D44, D45, D46, D47, D48, D49, D50, D51, D52, D53, D54, D55, D56, D57, D58: D; D_SOD-123
H2, H4, H6, H8: MountingHole; MountingHole_2.1mm
J4: JST_PH; JST_PH_S2B-PH-K_1x02_P2.00mm_Horizontal
L30, L31, L32, L33, L34, L35, L36, L37, L38, L39, L40, L41, L42, L43, L44, L45, L46, L47, L48, L49, L50, L51, L52, L53, L54, L55, L56, L57, L58: SK6812-MINI-E; LED_choc_6028R-ROT
R2: R_470Ω; R_0805_2012Metric_Pad1.20x1.40mm_HandSolder
S60: RotaryEncoder_Switch; ROT_Alps_EC11E-Switch
S62: S_SPDT; SW_SPDT_PCM12
SW30, SW31, SW32, SW33, SW34, SW35, SW36, SW37, SW38, SW39, SW40, SW41, SW42, SW43, SW44, SW45, SW46, SW47, SW48, SW49, SW50, SW51, SW52, SW53, SW54, SW55, SW56, SW57, SW58: SW_Push; SW_choc_v1_HS_CPG135001S30_1u
U4: SuperMini nRF52840; SuperMini_nRF52840_AH_USBup

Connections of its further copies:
+3.3V: C30.1, C31.1, C32.1, C33.1, C34.1, C35.1, C36.2, C37.2, C38.2, C39.2, C40.2, C41.2, C42.1, C43.1, C44.1, C45.1, C46.1, C47.1, C48.2, C49.2, C50.2, C51.2, C52.2, C53.2, C54.1, C55.1, C56.1, C57.1, C58.1, C60.1, L30.1 (VDD), L31.1 (VDD), L32.1 (VDD), L33.1 (VDD), L34.1 (VDD), L35.1 (VDD), L36.1 (VDD), L37.1 (VDD), L38.1 (VDD), L39.1 (VDD), L40.1 (VDD), L41.1 (VDD), L42.1 (VDD), L43.1 (VDD), L44.1 (VDD), L45.1 (VDD), L46.1 (VDD), L47.1 (VDD), L48.1 (VDD), L49.1 (VDD), L50.1 (VDD), L51.1 (VDD), L52.1 (VDD), L53.1 (VDD), L54.1 (VDD), L55.1 (VDD), L56.1 (VDD), L57.1 (VDD), L58.1 (VDD), U4.16 (3V3); also elsewhere on the board
/right/COL1: SW30.1, SW36.1, SW42.1, SW48.1, SW54.1, U4.18 (P0.29-LF)
/right/COL2: SW31.1, SW37.1, SW43.1, SW49.1, SW55.1, U4.11 (P1.04-LF)
/right/COL3: SW32.1, SW38.1, SW44.1, SW50.1, SW56.1, U4.10 (P0.11)
/right/COL4: SW33.1, SW39.1, SW45.1, SW51.1, SW57.1, U4.8 (P0.24)
/right/COL5: SW34.1, SW40.1, SW46.1, SW52.1, SW58.1, U4.9 (P1.00)
/right/COL6: SW35.1, SW41.1, SW47.1, SW53.1, U4.17 (P0.31-LF)
/right/LED_DAT: R2.2, U4.2 (P0.08)
/right/ROW1: D30.1 (K), D31.1 (K), D32.1 (K), D33.1 (K), D34.1 (K), D35.1 (K), U4.1 (P0.06)
/right/ROW2: D36.1 (K), D37.1 (K), D38.1 (K), D39.1 (K), D40.1 (K), D41.1 (K), U4.7 (P0.22)
/right/ROW3: D42.1 (K), D43.1 (K), D44.1 (K), D45.1 (K), D46.1 (K), D47.1 (K), U4.12 (P1.06-LF)
/right/ROW4: D48.1 (K), D49.1 (K), D50.1 (K), D51.1 (K), D52.1 (K), D53.1 (K), U4.23 (P0.10-LF)
/right/ROW5: D54.1 (K), D55.1 (K), D56.1 (K), D57.1 (K), D58.1 (K), U4.24 (P0.09-LF)
/right/R_E_1: S60.B, U4.25 (P1.01-LF)
/right/R_E_2: S60.A, U4.26 (P1.02-LF)
/right/R_E_S: S60.S1, U4.27 (P1.07-LF)
/right/SCL: U4.6 (P0.20); also elsewhere on the board
/right/SDA: U4.5 (P0.17); also elsewhere on the board
/right/VBAT: S62.1 (A), U4.13 (BAT+), U4.29 (BAT+); also elsewhere on the board
GND: C30.2, C31.2, C32.2, C33.2, C34.2, C35.2, C36.1, C37.1, C38.1, C39.1, C40.1, C41.1, C42.2, C43.2, C44.2, C45.2, C46.2, C47.2, C48.1, C49.1, C50.1, C51.1, C52.1, C53.1, C54.2, C55.2, C56.2, C57.2, C58.2, C60.2, J4.2, L30.4 (VSS), L31.4 (VSS), L32.4 (VSS), L33.4 (VSS), L34.4 (VSS), L35.4 (VSS), L36.4 (VSS), L37.4 (VSS), L38.4 (VSS), L39.4 (VSS), L40.4 (VSS), L41.4 (VSS), L42.4 (VSS), L43.4 (VSS), L44.4 (VSS), L45.4 (VSS), L46.4 (VSS), L47.4 (VSS), L48.4 (VSS), L49.4 (VSS), L50.4 (VSS), L51.4 (VSS), L52.4 (VSS), L53.4 (VSS), L54.4 (VSS), L55.4 (VSS), L56.4 (VSS), L57.4 (VSS), L58.4 (VSS), S60.C, S60.S2, U4.3 (GND), U4.4 (GND), U4.14 (GND), U4.28 (GND); also elsewhere on the board
unnamed: D30.2 (A), SW30.2
unnamed: D31.2 (A), SW31.2
unnamed: D32.2 (A), SW32.2
unnamed: D33.2 (A), SW33.2
unnamed: D34.2 (A), SW34.2
unnamed: D35.2 (A), SW35.2
unnamed: D36.2 (A), SW36.2
unnamed: D37.2 (A), SW37.2
unnamed: D38.2 (A), SW38.2
unnamed: D39.2 (A), SW39.2
unnamed: D40.2 (A), SW40.2
unnamed: D41.2 (A), SW41.2
unnamed: D42.2 (A), SW42.2
unnamed: D43.2 (A), SW43.2
unnamed: D44.2 (A), SW44.2
unnamed: D45.2 (A), SW45.2
unnamed: D46.2 (A), SW46.2
unnamed: D47.2 (A), SW47.2
unnamed: D48.2 (A), SW48.2
unnamed: D49.2 (A), SW49.2
unnamed: D50.2 (A), SW50.2
unnamed: D51.2 (A), SW51.2
unnamed: D52.2 (A), SW52.2
unnamed: D53.2 (A), SW53.2
unnamed: D54.2 (A), SW54.2
unnamed: D55.2 (A), SW55.2
unnamed: D56.2 (A), SW56.2
unnamed: D57.2 (A), SW57.2
unnamed: D58.2 (A), SW58.2
unnamed: J4.1, S62.2 (B)
unnamed: L30.3 (DIN), R2.1
unnamed: L30.2 (DOUT), L31.3 (DIN)
unnamed: L31.2 (DOUT), L32.3 (DIN)
unnamed: L32.2 (DOUT), L33.3 (DIN)
unnamed: L33.2 (DOUT), L34.3 (DIN)
unnamed: L34.2 (DOUT), L35.3 (DIN)
unnamed: L35.2 (DOUT), L41.3 (DIN)
unnamed: L36.3 (DIN), L37.2 (DOUT)
unnamed: L36.2 (DOUT), L42.3 (DIN)
unnamed: L37.3 (DIN), L38.2 (DOUT)
unnamed: L38.3 (DIN), L39.2 (DOUT)
unnamed: L39.3 (DIN), L40.2 (DOUT)
unnamed: L40.3 (DIN), L41.2 (DOUT)
unnamed: L42.2 (DOUT), L43.3 (DIN)
unnamed: L43.2 (DOUT), L44.3 (DIN)
unnamed: L44.2 (DOUT), L45.3 (DIN)
unnamed: L45.2 (DOUT), L46.3 (DIN)
unnamed: L46.2 (DOUT), L47.3 (DIN)
unnamed: L47.2 (DOUT), L53.3 (DIN)
unnamed: L48.3 (DIN), L49.2 (DOUT)
unnamed: L48.2 (DOUT), L54.3 (DIN)
unnamed: L49.3 (DIN), L50.2 (DOUT)
unnamed: L50.3 (DIN), L51.2 (DOUT)
unnamed: L51.3 (DIN), L52.2 (DOUT)
unnamed: L52.3 (DIN), L53.2 (DOUT)
unnamed: L54.2 (DOUT), L55.3 (DIN)
unnamed: L55.2 (DOUT), L56.3 (DIN)
unnamed: L56.2 (DOUT), L57.3 (DIN)
unnamed: L57.2 (DOUT), L58.3 (DIN)

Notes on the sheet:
LED
Display
Controller
Keyboard Matrix
Battery Connector

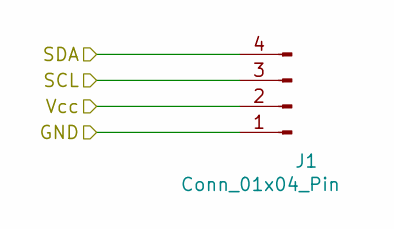
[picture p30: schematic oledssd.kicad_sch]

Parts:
J1: Conn_01x04_Pin; SSD1306-0.91-OLED-4pin-128x32

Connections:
/left/SCL: J1.3; also elsewhere on the board
/left/SDA: J1.4; also elsewhere on the board
/left/VBAT: J1.2; also elsewhere on the board
GND: J1.1; also elsewhere on the board

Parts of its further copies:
J2: Conn_01x04_Pin; SSD1306-0.91-OLED-4pin-128x32

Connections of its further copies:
/right/SCL: J2.3; also elsewhere on the board
/right/SDA: J2.4; also elsewhere on the board
/right/VBAT: J2.2; also elsewhere on the board
GND: J2.1; also elsewhere on the board

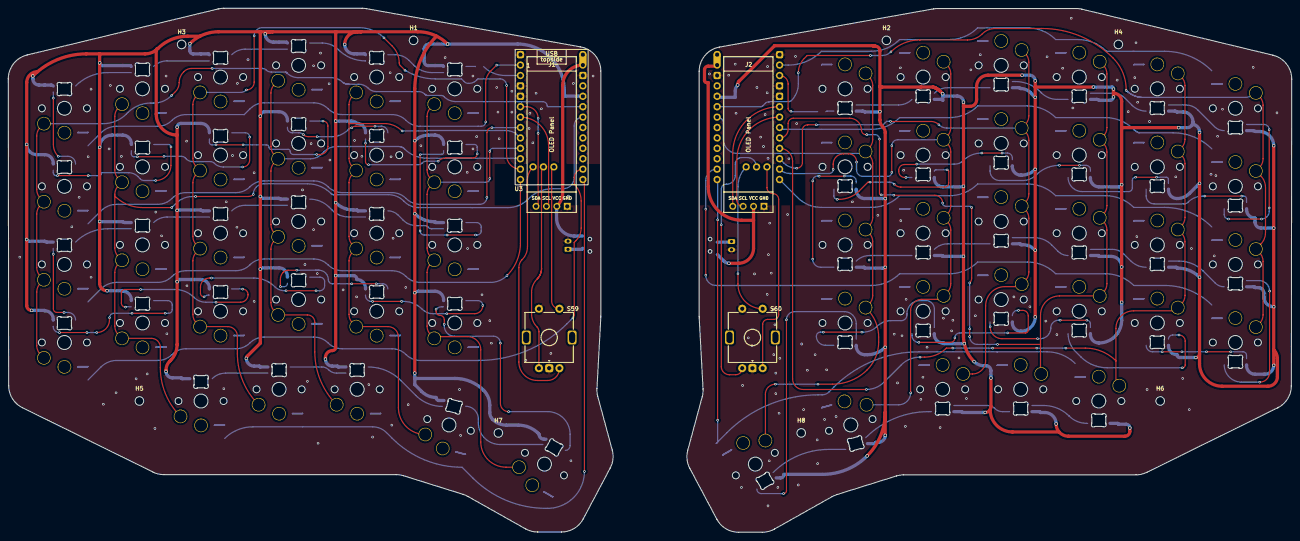
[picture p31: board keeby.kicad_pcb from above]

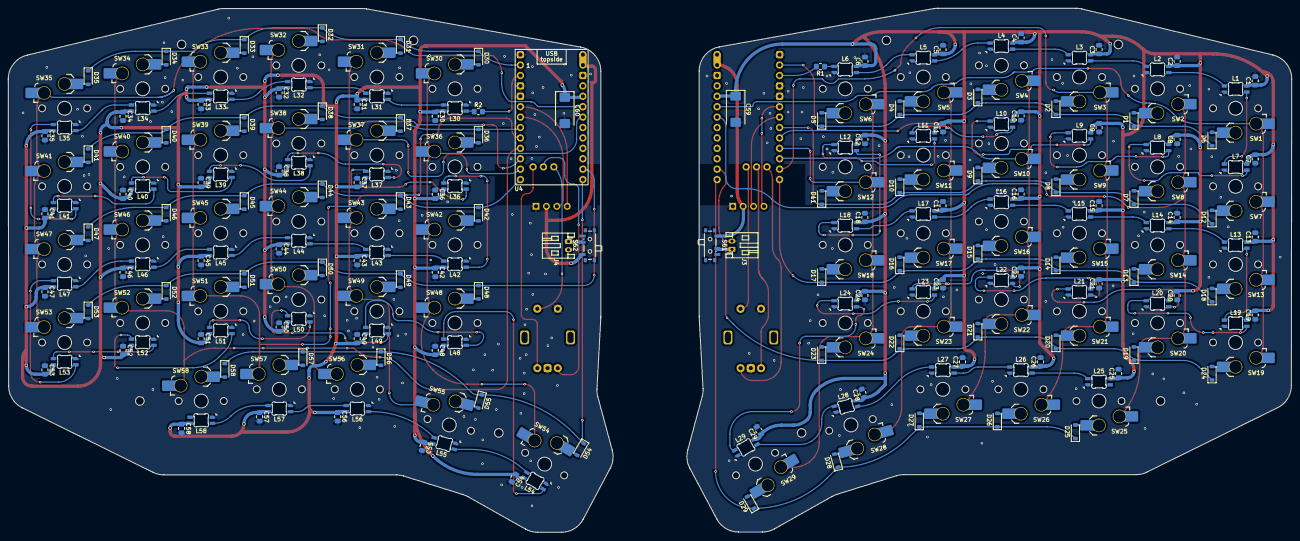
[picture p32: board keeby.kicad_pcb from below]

Board: 2 copper layers, 313.2 x 127.9 mm, 254 parts (241 on the bottom side), 156 nets.

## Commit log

2025-12-13 First Version?
    [keeby.kicad_sch, oledssd.kicad_sch]
2025-12-21 fix weird permission issue
    [keeby.kicad_pcb]
2025-12-25 start routing
    [half.kicad_sch, keeby.kicad_pcb]
2025-12-27 routed about half
    [half.kicad_sch, keeby.kicad_pcb]
2025-12-27 renamed properly
    [half.kicad_sch, keeby.kicad_pcb]
2025-12-27 placed components
    [half.kicad_sch, keeby.kicad_pcb]
2025-12-27 first route half
    [bom.csv, designators.csv, half.kicad_sch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]
2025-12-29 Updated BOM
    [keeby_BOM.csv]
2026-01-11 Updated Project Structure
    [bom.csv, designators.csv, half.kicad_sch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]
2026-02-15 Expand README with PCB and BOM details
    Added detailed sections for PCB routing, schematics, casing, and BOM.
2026-03-12 prepared outline
    [half.kicad_sch, keeby.kicad_pcb]
2026-03-12 started routing
    [keeby.kicad_pcb]
2026-03-12 Revert "progress??"
    This reverts commit cc348a77a973bafb10792190f59578297f7118eb.
    [keeby.kicad_pcb]
2026-03-13 fixing leds
    [freerouting.dsn, half.kicad_sch, keeby.kicad_pcb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]
2026-03-13 routed left side
    [keeby.kicad_pcb]
2026-03-13 addes case
    [Case.stl, half.kicad_sch, keeby.kicad_pcb]
2026-03-13 Add CAD documentation for keyboard case
    Added documentation for the keyboard case design in Onshape.
2026-03-13 fixing routing again
    [keeby.kicad_pcb]
2026-03-13 routed left
    [keeby.kicad_pcb]
2026-03-14 routed full
    [keeby.kicad_pcb]
2026-03-15 fixed board
    [keeby-Edge_Cuts.dxf, keeby-platev2.dxf, keeby.kicad_pcb]
2026-03-17 fixed board + updated README
    [BottomLeft.step, BottomRight.step, Case.step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]
2026-03-25 added decoupling capacitors
    [half.kicad_sch, keeby.kicad_pcb, oledssd.kicad_sch]
2026-03-26 routed again
    [half.kicad_sch, keeby.kicad_pcb]
2026-03-26 added fully assembled pic of keeby
    [bom.csv, designators.csv, keeby.step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]
2026-04-18 Update BOM for better readibility
